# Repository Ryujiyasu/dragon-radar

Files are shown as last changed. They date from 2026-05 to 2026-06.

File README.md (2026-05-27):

# Dragon Radar UWB

> ドラゴンボールの「ドラゴンレーダー」を現代の UWB (Ultra-Wide Band) 測距技術で実物として作るプロジェクト。
> DigiKey Make ONE Challenge 2026 (応募締切 **2026-06-22**) 出展作品。

円形 LCD を載せた手持ち端末が、周囲に散らばった UWB タグ (= ドラゴンボール) の **距離 + 方向 (AoA)** を 5 cm 精度で表示する。UI は 1980 年代バンダイの玩具版ドラゴンレーダーをオマージュ。

詳細仕様は [`dragon-radar-spec.md`](dragon-radar-spec.md)。背景・設計判断・進捗の物語は本 README とブログ記事 ([Related reading](#related-reading)) で記録する。

---

## What works today (2026-05-19 時点)

| 項目 | 状態 | 観測値 |
|---|---|---|
| 2BP ↔ 2DK ranging 成立 | ✅ | 50–60 秒で 200+ サンプル、両端 avg 距離差 < 0.5 cm |
| AoA 方位取得 | ✅ | -44° 安定 (左方向に 2DK 配置時) |
| ESP32-P4 で Bandai 風 UI 描画 | ✅ | 800×800、LVGL 9.5、5 Hz 更新 |
| QN9090 カスタム FW で `RADAR,t=...` ASCII 出力 | ✅ | 3 Mbps UART、~5 Hz |
| ESP32-P4 ↔ 2BP 物理 UART 配線 | ⏳ | TP48→GPIO47 / TP47→GPIO48 / GND、配線待ち |
| 2DK タグ × 7 個拡張 | 未 | Phase 3 以降 |
| 効果音 + BGM | 未 | Phase 4 以降 |

---

## 採用アーキテクチャ: Path C (二段構え)

```
Stage 1 (~6/22)  : Path C (QN9090 カスタム FW)         → DigiKey 応募
Stage 2 (~9月)   : 2DK タグ × 7 個拡張 + 演出           → Maker Faire Tokyo 2026
Stage 3 (将来)   : Path B (ESP32 ↔ SR150 SPI 直結) 移植 → QN9090 を取り払いコスト/サイズ削減
```

Path C は QN9090 (Murata EVK 標準搭載の host MCU) をそのまま使い、その上で動くファームを NXP UWBIOT SDK ベースで自作する路線。

---

## ハードウェア

| 役割 | 型番 | 数 |
|---|---|---|
| プレイヤー機 UI / ホスト | **Waveshare ESP32-P4-WIFI6-Touch-LCD-3.4C** (800×800 round IPS) | 1 |
| 旧 UI 予備 | Waveshare ESP32-S3-Touch-LCD-1.85 | 1 |
| プレイヤー機 UWB (initiator + AoA) | **Murata Type 2BP EVK Rev 4.1** (SR150 + QN9090) | 1 |
| タグ (responder) | **Murata Type 2DK EVK** (SR040 + QN9090) | 2 |
| デバッガ (任意) | NXP MCU-Link Pro | 1 |
| 書込ツール | **`spsdk` (`dk6prog`)** — USB ISP 経由、SWD 不要 | — |

> ⚠️ 技適制約: ESP32-P4 ボード上の ESP32-C6 (WiFi6 コンパニオン) は技適マーク未確認のため、**WiFi/BT は使用しない方針**。2BP ↔ ESP32-P4 は物理配線で接続する。詳細は [#5 技適記事](https://yasu-home.com/?p=37) 参照。

---

## システム構成 (Path C / Stage 1)

```
┌──────────────────────────────────┐         ┌───────────────────────────────┐
│   ESP32-P4 (Waveshare 3.4C)      │         │   Murata 2BP EVK Rev 4.1      │
│                                  │  TP48   │                               │
│   LVGL 9 (Bandai 風 UI)          │ ◄────── │   QN9090 (UCI host)           │
│   uwb_uart_task (3 Mbps)         │ GPIO47  │     │                         │
│   parse RADAR ASCII              │   GND   │   SR150  ◄── UWB 6.5GHz ──┐   │
│   polar → radar pixel            │ ──────  │     (initiator + 3-ant AoA)│   │
└──────────────────────────────────┘         └───────────────────────────────┘
                                                                              │
                                              ┌───────────────────────────────┘
                                              ▼
                                    ┌───────────────────────────────┐
                                    │   Murata 2DK EVK × 2          │
                                    │   QN9090 (Murata standalone)  │
                                    │   SR040 (responder)           │
                                    └───────────────────────────────┘
```

UART payload format (QN9090 が 3 Mbps で吐く 1 行):

```
APP     :INFO :RADAR,t=0,d=21,az=-44.18,el=-60.0,st=0
                       │   │      │           │       │
                       │   │      │           │       └── status: 0=OK
                       │   │      │           └────────── elevation (Q9.7 deg)
                       │   │      └────────────────────── azimuth   (Q9.7 deg)
                       │   └────────────────────────────── distance (cm)
                       └──────────────────────────────── tag id
```

---

## SDK バージョン整合 (最重要)

2BP (SR150) と 2DK (SR040) は **UCI プロトコルの世代を揃えないと ranging が成立しない**。詳細は [#3 UCI 世代差記事](https://yasu-home.com/?p=35)。

| EVK | 採用 FW | UCI 世代 | session ID |
|---|---|---|---|
| 2BP (SR150) | NXP UWBIOT SDK **v04.04.03** ベースのカスタム FW | **1.31** | 0x11223344 |
| 2DK (SR040) | Murata Standalone **v04.03.14** プリビルド (校正済) | **1.31** | 0x11223344 |

UCI v2.0 系 (v04.06.00+) と v1.x 系を混在させると、RANGE_DATA_NTF の `session ID` フィールドの意味が変わる (handle vs ID) ためペアリング不成立。

---

## ディレクトリ

```
dragon-radar/
├── firmware/
│   ├── esp32-p4/                   # ESP-IDF v5.5.4 (UI + UART parser + game)
│   │   ├── main/
│   │   │   ├── ui/                 # radar_view, theme (Bandai colors)
│   │   │   ├── uwb/                # uwb_uart (3Mbps RADAR parser), uwb_filter
│   │   │   ├── game/               # ドラゴンボール検知ゲーム
│   │   │   ├── audio/              # I2S WAV (BGM / SE)
│   │   │   └── storage/            # microSD (FATFS)
│   │   └── sdkconfig.defaults
│   ├── 2bp-fw/                     # 2BP の QN9090 用カスタム FW (Path C)
│   ├── 2dk-fw/                     # 2DK の QN9090 用 FW (将来 Responder 自前ビルド)
│   └── 2bp-config/                 # ★ NDA 配下、gitignore
│       ├── docs/                   # Murata 提供 PDF
│       ├── sdk/                    # NXP UWBIOT SDK + Murata パッチ
│       ├── firmware-backups/       # 工場 FW dk6prog ダンプ
│       └── firmware-builds/        # 自前ビルド済みバイナリ
├── docs/
│   └── 2bp-protocol.md             # ESP32 ↔ QN9090 ASCII プロトコル仕様
├── assets/
│   ├── audio/                      # WAV (神龍 / ウーロン / SE)
│   └── images/                     # PNG (光点, 龍, 星)
└── tools/                          # PC 側スクリプト
```

---

## ビルド

### ESP32-P4 ファーム

```bash
. ~/esp/esp-idf-v5.5/export.sh
cd dragon-radar/firmware/esp32-p4
idf.py build
idf.py -p /dev/ttyACM0 flash monitor
```

GPIO 割当 ([uwb_uart.h](dragon-radar/firmware/esp32-p4/main/uwb/uwb_uart.h)):

| ESP32-P4 GPIO | 2BP EVK TP | 信号 |
|---|---|---|
| GPIO 47 (UART1 RX) | **TP48** | RADAR ASCII (3 Mbps) |
| GPIO 48 (UART1 TX) | **TP47** | 制御送信 (optional) |
| GND | GND (TP29 等) | — |

⚠️ 番号交差注意: 2BP **TP48** ↔ ESP32 **GPIO47**、2BP **TP47** ↔ ESP32 **GPIO48**。

### 2BP QN9090 カスタム FW (NXP UWBIOT SDK)

MCUXpresso IDE の headless build を使う ([#2 MCUXpresso 記事](https://yasu-home.com/?p=34))。

```bash
xvfb-run --auto-servernum --server-args="-screen 0 1024x768x24" \
  /usr/local/mcuxpressoide-25.6.136/ide/mcuxpressoide \
  -nosplash \
  -application org.eclipse.cdt.managedbuilder.core.headlessbuild \
  -data /tmp/mcux-ws \
  -import dragon-radar/firmware/2bp-config/sdk/UWBIOT_SR150_v04.04.03_MCUx/uwbiot-top/project/RhodesV4_SE \
  -cleanBuild "RhodesV4_SE/Debug"
```

出力: `.../project/RhodesV4_SE/Debug/RhodesV4_SE.bin` (約 350 KB、9.6 秒)。

### 2BP に書込 (USB ISP / SWD 不要)

`dk6prog` (SPSDK 同梱) で書き込む ([#1 dk6prog 記事](https://yasu-home.com/?p=33))。

```bash
# 1. EVK のみ単独で USB 接続、ISP ボタン押しながらリセット
dk6prog listdev                                                    # DM86TTWC を確認
dk6prog -d DM86TTWC read 0 0x9DE00 -o factory_backup.bin           # 工場 FW バックアップ (1 度だけ)
dk6prog -d DM86TTWC erase 0 0x9DE00
dk6prog -d DM86TTWC write 0 dragon-radar/firmware/2bp-config/firmware-builds/2bp_dragon_radar_v0.1.bin
```

### 2DK は Murata 出荷 FW のまま使う

2DK は Murata が標準で `2dk_controlee_v04.03.14.bin` を焼いて出荷しており、これがそのまま v1.31 UCI の responder として動く。**書換不要**。

---

## 開発フェーズ

- [x] **Phase 0**: 環境準備 (NXP SDK / MCUXpresso / SPSDK / Waveshare BSP) + 工場 FW バックアップ
- [x] **Phase 1**: ESP32-P4 + LVGL Bandai レーダー UI (ダミーデータ) ✅ 2026-05-19
- [x] **Phase 2a**: NXP UWBIOT SDK v04.04.03 ヘッドレスビルド検証 ✅ 5/19
- [x] **Phase 2b**: `printRangingData` 改造で `RADAR,t=...` ASCII 出力 ✅ 5/19
- [x] **Phase 2c**: 2BP にカスタム FW 書込 + 3 Mbps UART で実機 RADAR 出力確認 ✅ 5/19
- [x] **Phase 2d-1〜4**: EVK ピン特定 + ESP32-P4 GPIO 選定 + UART parser + LVGL 連携実装 ✅ 5/19
- [ ] **Phase 2d-5**: 物理配線 (TP48→GPIO47 等) + 実機テスト (LCD に実距離+AoA 表示)
- [ ] **Phase 3**: 2DK タグ拡張 (2 個 → 7 個) + round-robin スケジューラ
- [ ] **Phase 4**: 音声 (神龍/ウーロン) + SE + BGM + 検知ゲーム
- [ ] **Phase 5**: 筐体 CAD + 3D プリント + 組立
- [ ] **Phase 6**: デモ動画撮影 + DigiKey 応募 (~6/22)
- [ ] **Phase 7**: Maker Faire Tokyo 2026 (~9/5-6) 持込

---

## 制約と教訓

### 技適制約

Waveshare ESP32-P4-WIFI6-Touch-LCD-3.4C 上の ESP32-C6 (WiFi6 コンパニオン) は技適マーク未確認。
公開展示 (DigiKey、Maker Faire) では電波法的にグレーなので、**WiFi/BT を一切 init しない設計**。
ESP32-P4 ↔ 2BP は物理 UART 配線で代替する。詳細: [#5 技適記事](https://yasu-home.com/?p=37)。

### NDA 配下のファイル

`dragon-radar/firmware/2bp-config/` 以下は **Murata NDA 配下** (公式 PDF、NXP UWBIOT SDK、工場 FW バックアップ等)。
gitignore で完全除外、Git に絶対コミットしない。`.gitignore` で `*` + `!.gitignore` パターン。

`my.murata.com` から取得した PDF/SDK は配布禁止。これらに依存する手順は本 README とブログでは技術概念のみ記述し、ソースコード抜粋やキャリブレーション値は載せない。

### UCI 世代揃え

異なる NXP UWB チップ (SR150 / SR040) を組ませる時は SDK の UCI 仕様世代を揃える。
NTF の session ID フィールドが見た目同じでも、v1.x (ID) と v2.0 (Handle) で意味が違う。
詳細: [#3 UCI 世代差記事](https://yasu-home.com/?p=35)。

---

## Related reading

開発過程の知見をブログ記事に分割公開している (https://yasu-home.com 「IoT・組込み」カテゴリ):

| # | 記事 | URL |
|---|---|---|
| 0 | 連載 #0 ドラゴンレーダーを真面目に作る | [https://yasu-home.com/?p=38](https://yasu-home.com/?p=38) |
| 1 | dk6prog (SPSDK) で QN9090 を USB ISP だけで焼く | [https://yasu-home.com/?p=33](https://yasu-home.com/?p=33) |
| 2 | MCUXpresso IDE の headless build で組込ファームを 10 秒で回す | [https://yasu-home.com/?p=34](https://yasu-home.com/?p=34) |
| 3 | UWB ranging が動かない真犯人は「UCI 世代差」だった話 | [https://yasu-home.com/?p=35](https://yasu-home.com/?p=35) |
| 4 | ESP32-P4 × LVGL で「バンダイ ドラゴンレーダー」風 UI を本気で再現する | [https://yasu-home.com/?p=36](https://yasu-home.com/?p=36) |
| 5 | 技適未確認の WiFi ボードを国内コンテストに出すなら何を捨てるか | [https://yasu-home.com/?p=37](https://yasu-home.com/?p=37) |

---

## ライセンス

本リポジトリ内のオリジナルコード (主に `dragon-radar/firmware/esp32-p4/`) はライセンス未確定。
`dragon-radar/firmware/2bp-config/` 以下は NXP / Murata の NDA 配下で再配布不可。
最終的に MIT または Apache-2.0 で公開予定 (応募完了後)。

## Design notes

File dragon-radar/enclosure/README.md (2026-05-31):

# Dragon Radar UWB — 筐体 (Enclosure)

DigiKey Make ONE Challenge 2026 / プレイヤー機の 3D プリント筐体。

- CAD: **OpenSCAD** (パラメトリック、git 管理)
- 印刷: **FDM / PLA / ベッド ~220mm** (ø 一体造形、分割なし)
- ソース: [`dragon-radar-enclosure.scad`](dragon-radar-enclosure.scad)
- 実測: [`MEASURE.md`](MEASURE.md) — 現物を測って `[MEASURE]/[VERIFY]` を確定する記入シート

## 現状: v0.7 (実機適合 + 印刷前レビュー済)

3 部品クラムシェル。**ボード/ボタン現物を実測してモデル確定**、印刷前の多エージェント
レビューで確定8件(critical含む)を修正済み。外径 **ø122.6 × 厚26.9mm**。
残: 現物合わせの [VERIFY] (バレル径・ナット径・コネクタ開口角度)=テストプリントで詰める。

実測で判明した構成 (→ [`MEASURE.md`](MEASURE.md)):
- 前面=丸ディスプレイ **ø115** (有効 ø87.6) / 背面=四角キャリア **85.5×65** / 総厚 **14**
- マウントネジ4本=上下非対称な台形 (X±41.8 / 左Y32 / 右Y39)
- コネクタ: USB-C(上辺)→**底270°** / USB-A→右0° / microSD→左180° (`carrier_angle=180`)
- ボード固定: **二段締め** (カラーでボード⇔ディスプレイ → バックカバー4本で筐体固定)
- ボタン: ø12メタル(全長24/頭1.7/頭〜ナット6) → タレット cap1.8/protrude14/bore16.5

### 印刷前レビューで修正した主な点 (v0.6→v0.7)
- 🔴 **スナップ溝がトング壁0.4mmを貫通→前面リップ分離** を `wall 2.4→3.2` 等で解消(残壁1.0mm)
- 🟠 着座シェルフをガラス背面平面へ / スカラップ肉盛りを z 拘束(前後面の突き抜け防止)
- 🟡 USB-A開口 11→13mm、ナットねじ代確保(cap 1.8)
- 先行: タレットが角度合成で180°にズレmicroSDと衝突 → +X基準に統一し天面90°へ

```
[前面ベゼル] 表示窓 ø91.6 + 段付きスカート + 環状スナップビード + タレット逃げ
[本体タブ]   側壁 + 段付きトング(溝) + 着座シェルフ + バックカバー用ボス
             + コネクタ開口(底) + 天面ボタンタレット + フィンガースカラップ(3/9時)
[バックカバー] M3×4 ネジ留め + 嵌合リップ + 配線通気
```

### フィンガースカラップ (v0.4)

両手持ちの 3/9 時 (0/180°) に親指レスト。側壁 2.4mm + 内側モジュールで深掘り不可のため、
**局所肉盛りレンズ + 浅い凹み** で最薄壁 ~2.4mm を確保。`scallop_angles=[]` で無効化、
高さ/深さは `scallop_*` 変数で調整。ベゼル占有域 (z≤-7) と干渉しないよう中心 z=-14.5 に配置。

> 副次変更: placeholder コネクタを**底側 (250/270/290°)** に集約 (スカラップと干渉回避 +
> ケーブル底出しが自然)。実機角度は [MEASURE] で確定する。

> 🐞 修正: ネジボスが内壁に 0.5mm 届かず**浮きソリッド**になっていた (CGAL Volumes=6 で発覚)。
> `screw_pcd` を外側へ寄せて壁と一体化 (Volumes=2 = 単一ソリッド)。

### 天面ボタンタレット (v0.3)

⚠ **設計上の制約**: モジュール(ø108)と内壁(ø116)の隙間は片側 ~4mm しかなく、
ø12 ボタンの端子(径方向 15-20mm)を画面高さにラジアル配置すると**必ずモジュールに干渉**する。
→ ボタン専用の張り出し容積=**中空タレット**を天面(+Y, 12時)に設け、端子はタレット内に収め、
**細い配線のみ**を環状隙間→後方空洞へ通す。Bandai ラジアンドラップ天面ボタンと同趣。

| パラメータ | 値 | 備考 |
|---|---|---|
| `turret_od` / `turret_protrude` | ~ø21.7 / 18mm | 突出長 ≈ ボタン全長−パネル [VERIFY] |
| `turret_bore` | ø16.5 | ナット/端子の逃げ径 [VERIFY] |
| `button_dia` / `turret_cap_th` | ø12.3 / 3mm | パネル穴 / パネル厚(≤~5) [VERIFY] |
| `wire_hole_dia` | ø5 | 配線通路(後方空洞へ) |

ボタンは Phase4-5 で配線済の MKBKLLJY 現物がある → 全長・端子長・パネル厚を実測し
`turret_protrude` / `turret_bore` / `turret_cap_th` を確定すること。

### 固定方式 (v0.2 確定)

| 接合 | 方式 | 理由 |
|---|---|---|
| ベゼル ⇔ 本体 | **環状スナップフィット** (連続ビード+溝) | 丸物は自己整列、応力が全周分散で PLA でも堅牢。前面ネジ無しで玩具的外観。工具レス開閉。 |
| バックカバー ⇔ 本体 | **M3 セルフタップ ×4** (後方空洞のボス) | 電池/配線/デバッグで開ける前提。背面ネジは外観に影響せず確実。 |

スナップ諸元: スカート厚 `skirt_wall=2.0`、トング高 `tongue_h=7.0`、ビード/溝 径方向 `snap_bead=0.9`、
リードイン `snap_lead=0.8`。外周は本体壁とスカートで **ø121 面一**。
嵌合確認は `-D clip=true` で Y>=0 半割り断面を表示できる。

## レンダリング / 書き出し

OpenSCAD GUI で開き、先頭の `part` 変数を切替えてプレビュー。
印刷用 STL は一括スクリプトで書き出す (生成物は `stl/`、git 管理外):

```bash
# PATH に openscad があれば:
./export-stl.sh
# AppImage を展開して使う場合:
OPENSCAD=/path/to/AppRun FN=180 ./export-stl.sh
```

`part` の値: `assembly`(確認) / `bezel` / `body` / `back` / `board`(mock) /
`coupon_body` / `coupon_bezel` / `coupon`(嵌合確認) / `-D clip=true`(半割り断面)

### スナップ試しクーポン (テストプリント)

`coupon_body` と `coupon_bezel` は嵌合部だけを底側 55° アークで切り出した小片
(実部品と同一ジオメトリ)。フル印刷の前にこの 2 つを印刷して
**寸法フィット** (ビードが乗り越える/座る、`fit_gap` の渋さ、リードインの掛かり) を検証する。

- 検証できる: 径方向の嵌め合い・ビード乗り越え・座面
- 検証しきれない: 全周フープのしなり「カチッ」感 (短アークは実機より硬い) → 最終はベゼル実物で確認
- 調整する変数: `snap_bead`(0.9) / `fit_gap`(0.3) / `snap_lead`(0.8)

### 印刷の向き (推奨)

| 部品 | 向き | サポート |
|---|---|---|
| bezel | 前面を下 (窓側を造形ベッド) | 不要〜軽微。スカート内ビードはオーバーハングだが lead で自立 |
| body | 開口(前面)を上、バック側を下 | タレットの張り出し下面に少量。トング/溝は縦で良好 |
| back | 平面を下 | 不要 |
| coupon | body=トングを上 / bezel=面を下 | 不要 |

## 寸法の出典と確度

### [確定] Waveshare 3.4C 実寸 (wiki 寸法図 + CNX 記事)

| 項目 | 値 | 出典 |
|---|---|---|
| ガラス/前面外形 | **ø115 mm** | CNX「115×115 Outline」 |
| 有効表示エリア | **ø87.6 mm** (800×800, 3.4") | CNX「87.6×87.6 Display area」 |
| 前面ガラス厚 | ~6 mm | wiki 側面図 (4C 図から類推) |
| モジュール総厚 | ~15 mm | wiki 側面図 |

> 注: wiki 寸法図 (ø126 / ø101.52 / 厚15) は **4 インチ版 (4C)** のもの。
> 3.4C はそれより一回り小さい ø115 / ø87.6。仕様書の「ø110」想定より実機は大きく、
> **筐体外径は ~ø121 mm**(下記計算)になる。`dragon-radar-spec.md` の筐体寸法は要更新。

出典:
- https://www.waveshare.com/wiki/ESP32-P4-WIFI6-Touch-LCD-3.4C
- https://www.cnx-software.com/2025/06/01/esp32-p4-development-board-features-3-4-inch-or-4-inch-round-ips-touchscreen-display/

### [要実測 MEASURE] ボード到着後に現物確定する項目

`.scad` 内で `[MEASURE]` 印を付けた変数。実測値を入れれば全体が追従する。

| 変数 | 仮置き | 確定方法 |
|---|---|---|
| `mount_count` / `mount_pcd` / `mount_hole_dia` / `mount_angle0` | 4 / ø105 / ø2.5 / 45° | マウント穴を実測 (PCD・本数・径・基準角) |
| USB-C / USB-OTG / microSD のリム角度・開口寸法 | `connector_cutout()` 3 箇所が仮 | 各コネクタの周方向位置と高さを実測 |
| `back_clear` | 8 mm | 背面コネクタ群の最大突出 + 電池/配線スペース |
| `button_z` | スタック中央 | MKBKLLJY ボタンの実装高さ |

### 筐体派生寸法 (現状の仮値での計算結果)

| 寸法 | 値 |
|---|---|
| 内壁径 `inner_dia` | ~116.2 mm |
| **外径 `outer_dia`** | **~121.0 mm** |
| 表示窓径 `window_dia` | ~91.6 mm (有効表示 ø87.6 を完全露出) |
| **筐体総厚 `outer_depth`** | **~27.9 mm** (仕様目標 30mm 以内 ✅) |

## 印刷設定 (FDM / PLA、初版の目安)

| 項目 | 値 | 備考 |
|---|---|---|
| ノズル / 層厚 | 0.4mm / 0.2mm | 側壁 `wall=2.4` は 0.4×6 で割り切れる |
| 壁ライン数 | 3–4 | |
| インフィル | 15–20% gyroid | |
| サポート | ベゼル窓まわり程度 | 各部品は概ね自立印刷向き |
| 向き | ベゼル=窓を上 / 本体=開口を上 / バック=平面下 | |

## 次のステップ (ボード到着前にできる事 / 到着後)

- [x] `dragon-radar-spec.md` の筐体寸法を ø110→ø121 に更新
- [x] ベゼル⇔本体の固定方式決定 → 環状スナップ + バックM3ネジ (v0.2)
- [x] 天面ボタンタレット (MKBKLLJY ø12+LED) を配置・中ぐり・配線通路 (v0.3)
- [x] フィンガースカラップ (3/9時) + ネジボス浮き修正 (v0.4)
- [x] スナップ試しクーポン + STL一括書き出し (B-1/B-3)
- [ ] 【A】現物実測: コネクタ角度/マウント穴 PCD/ボタン各寸法 → 各 [MEASURE]/[VERIFY] 確定 ← 次
- [ ] ボタン現物を実測 → `turret_protrude`/`turret_bore`/`turret_cap_th` 確定
- [ ] マウントボスをネジ種 (M2.5 セルフタップ or インサート) に合わせて確定
- [ ] ストラップ/手持ち形状、滑り止め
- [ ] テストプリント (スナップ嵌合 + タレット嵌め込みの現物確認)

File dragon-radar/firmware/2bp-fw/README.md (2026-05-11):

# 2BP QN9090 カスタムファームウェア (Path C)

ESP32 ↔ 2BP の自前 ASCII プロトコル ([../../docs/2bp-protocol.md](../../docs/2bp-protocol.md)) を喋り、内部で SR150 を UCI で叩いて round-robin Unicast TWR を実行する QN9090 用ファーム。

## 必要な前提

- NXP UWBIOT SDK SR150 v04.06.00 (要 NXP MyAccount)
- Murata 提供パッチ (`2bp_prebuilt_*.patch`、my.murata.com から取得)
- MCUXpresso IDE (Linux 版、無料)
- MCU-Link Pro (SWD 書込用)
- ARM GCC toolchain (`arm-none-eabi-gcc`)

## SDK 配置 (gitignore 内)

NXP からダウンロードした SDK は **NDA 配下** のため、コミット禁止。下記に展開する:

```
firmware/2bp-config/
├── docs/                             # Murata PDF (取得済)
└── sdk/                              # ★ ここに SDK を展開
    ├── UWBIOT_SR150_*_SEGGER/
    └── 2bp_prebuilt_*.patch
```

`firmware/2bp-config/.gitignore` で全配下が除外されているので安全。

## ビルド手順 (Phase 1 で確定)

```bash
# 1. SDK ディレクトリへ
cd firmware/2bp-config/sdk/UWBIOT_SR150_*_SEGGER/uwbiot-top

# 2. Murata パッチ適用 (Quick Start PDF 参照)
patch -p0 < ../2bp_prebuilt_*.patch

# 3. デモ ranging controller を 2BP の QN9090 用に make
cd boards/Host/Rhodes4
make demo_ranging_controller TARGET=QN9090

# 4. JLinkExe で書込み (MCU-Link Pro が J-Link 互換ファーム)
JLinkExe -device QN9030 -if SWD -speed 4000 -CommandFile flash.jlink
```

## 開発ステップ

| Phase | やること |
|---|---|
| 1 | SDK + パッチ適用 → Murata 出荷 FW 相当をビルド・書込・動作確認 |
| 2 | UART パーサ (ASCII) を組み込み、`VER`/`RANGE` (1タグ) 実装 |
| 3 | `SET_TAGS` / round-robin (2 タグ対応) |
| 7 | round-robin の 7 タグ対応、サイクル時間最適化 |

## ファイル配置 (Phase 2 で実装予定)

```
2bp-fw/
├── README.md       (このファイル)
├── src/
│   ├── main.c          # FreeRTOS エントリ
│   ├── uart_cmd.c/h    # ASCII コマンドパーサ
│   ├── ranging.c/h     # round-robin スケジューラ
│   └── config.h        # SR150 設定、タグ MAC 一覧
└── prj/                # MCUXpresso プロジェクト一式
```

## デバッグ Tips

- 元の Murata プリビルド FW に戻すには Phase 0 で取得した `firmware-backups/2bp_qn9090.bin` を JLink で書き戻す
- UART 出力は MCU-Link Pro の Bridge UART で覗ける (Virtual COM)
- SR150 への UCI コマンド送信前に必ず `phNxpUciHal_init()` を呼ぶ (校正データロード)

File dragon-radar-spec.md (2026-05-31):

# Dragon Radar UWB - 開発指示書 (Path C / 二段構え版)

DigiKey Make ONE Challenge 2026 応募作品。Murata UWB EVK + Waveshare ESP32-S3-Touch-LCD-1.85 でドラゴンレーダー風の宝探しデバイスを作る。子供と公園で 2-7 個のタグを探し、全部集めると神龍が召喚されてウーロンが「ギャルのパンティおくれーっ」と叫ぶ。

応募締切: **2026-06-22 23:59** (残り **42 日** / 起算 2026-05-11)
GW (4/29-5/6) 終了、平日モード移行。子守再開済で開発時間は **夜 + 週末**。
本ドキュメントは Claude Code への開発指示書として使用する。

---

## 採用方針: **Path C** (QN9090 ファーム書換え)

### Path 比較サマリ (詳細別途検討済)

| Path | 概要 | 採否 | 理由 |
|---|---|---|---|
| Path A | Murata プリビルド FW のまま | ❌ | 2DK が Initiator 固定でタグにできない |
| Path B | QN9090 erase + ESP32 が SR150 を SPI 直叩き | ❌ (今回) | 工数大、2BP 1個で破壊リスク高 |
| **Path C** | **QN9090 にカスタム FW、ESP32 ↔ QN9090 は UART** | ✅ **採用** | 工数中、ハード改造ゼロ、戻せる |

### 二段構え戦略

```
[Stage 1] 5月中: Path C で実装 → 6/22 応募 (実演 2 タグ + 演出で 7 タグ)
[Stage 2] 7-8月: Path B (ESP32 で SR150 を直接制御) に移植チャレンジ
[Stage 3] 9/5-6: Maker Faire Tokyo 2026 出展 (進化版)
```

---

## ハードウェア構成

### 現有機材 (2026-05-03 時点)

| 役割 | 型番 | 数 | 状態 / 備考 |
|---|---|---|---|
| プレイヤー機 UI (旧) | Waveshare ESP32-S3-Touch-LCD-1.85 | 1 | ESP32-S3 + 1.85" 丸型 LCD (360×360, ST77916)。画面が小さく、Bandai 玩具感は出るが「ガチ路線」のため格上げ予定 |
| **プレイヤー機 UI (新) ⭐** | **Waveshare ESP32-P4-WIFI6-Touch-LCD-3.4C** | **1 (発注予定)** | **ESP32-P4 + ESP32-C6 (Wi-Fi6/BT5、未使用)、3.4" 丸型 LCD (800×800, MIPI-DSI 2-lane)、10 点タッチ、デュアルマイク、microSD。$80-90、DigiKey 発注予定** |
| プレイヤー機 UWB | Murata Type 2BP EVK (LBUA0VG2BP-EVK-P) | 1 | NXP **SR150** (距離+AoA可) + QN9090 MCU。Path C では QN9090 にカスタム FW を焼く |
| タグ #1, #2 | Murata Type 2DK EVK (LBUA2ZZ2DK-EVK) | 2 | NXP **SR040** (距離のみ) + QN9090 MCU。CR2032 駆動可、隠して放置できる。Path C で Responder 化 |
| デバッガ/SWD 書込 | NXP MCU-Link Pro | 1 | QN9090 へのカスタム FW 書込用、Bridge UART/Target Power 機能あり |
| 用途未確定 | EA-WO1391-1228 (Embedded Artists 系?) | 1 | Phase 0 で正体特定すること |

### UI 操作系の仕様 (確定)

**物理ボタン × 1 + タッチスクリーン + 音声トリガ の三段構え**:

| 操作系 | 用途 | 実装時期 |
|---|---|---|
| **物理ボタン (MKBKLLJY ø12mm メタル + 緑 LED、配線済)** | スキャン開始 / 一時停止 (アニメリスペクト) + 神龍 LED 演出 | Phase 4-5 |
| **タッチスクリーン (10 点)** | ズーム、タグ情報表示、設定メニュー | Phase 2-3 |
| **音声トリガ (デュアルマイク)** | 「ドラゴンボールを探せ!」で起動 | Phase 7 (Maker Faire 用) |

筐体上部に **MKBKLLJY 緑 LED モメンタリ ボタン (ø12mm)** を配置 (Bandai 玩具と同位置)。
押下時に「ピッ」効果音 (VOICEVOX 生成)、待機中は LED 呼吸光、神龍召喚時は LED 高速点滅。
LED は 12V 仕様なので、ESP32 GPIO から MOSFET で 5V (USB-C 5V) を ON/OFF する構成。

### 機材についての追記
- 2BP EVK のヘッダピン (10ピン×2列) が一部曲がっているが、**Path C では USB ケーブルのみで動作するため影響なし**
- 2BP EVK は **1 個しか保有しない方針** (高価なため、破損時のみ追加発注)
- 2DK EVK の追加 5 個は **6/22 応募後 (7月頃) に発注予定** (Maker Faire 7 タグ拡張用)
- **プレイヤー機 LCD は 1.85" → 3.4" に格上げ決定** (動画映え重視、ESP32-S3 → ESP32-P4 への移行が必要):
  - 旧 1.85" (ESP32-S3-Touch-LCD-1.85) は予備 / Phase 2 検証用に保管
  - 新 3.4" (ESP32-P4-WIFI6-Touch-LCD-3.4C) は 5/4 発注、5/12 頃着想定
  - 筐体: **外径 ~ø122.6mm × 厚 ~26.9mm** (両手持ち or 大人片手、Bandai より大きいが解像度 800×800 で迫力)
    - 3.4C 実寸(実測確定): 前面=丸ディスプレイ **ø115**(有効 ø87.6) / 背面=四角キャリア **85.5×65** / モジュール総厚 **14**
    - OpenSCAD パラメトリック筐体は [`dragon-radar/enclosure/`](dragon-radar/enclosure/) (v0.7: 実機適合 + 印刷前多エージェントレビュー済)
    - マウントネジ4本=上下非対称台形、コネクタ USB-C底/USB-A右/microSD左、天面ボタンタレット、二段締め固定。残は現物合わせ [VERIFY]
  - 移行作業: ESP-IDF target esp32s3→esp32p4、display_init.c (SPI ST77916 → MIPI-DSI)、LVGL 寸法定数 (360 → 800)、半日〜1日工数

### 9月 Maker Faire 用追加発注 (7月予定)

| 部品 | 数 | 概算 |
|---|---|---|
| 2DK EVK 追加 | 5 | ~$450 |
| (オプション) 自作タグ PCB 部品一式 | 1 セット | ~$300 |

---

## システムアーキテクチャ (Path C)

```
[ プレイヤー機 (筐体内部) ]
┌─────────────────────────────────────────────┐
│ Waveshare ESP32-S3-Touch-LCD-1.85          │
│  ├─ LVGL UI (丸型レーダー)                  │
│  ├─ ゲームステートマシン                    │
│  ├─ 音声再生 (I2S)                         │
│  ├─ microSD (asset)                         │
│  └─ UART パーサ (シンプル ASCII)            │
└──────┬──────────────────────────────────────┘
       │ UART or USB-CDC
       │ "RANGE" → "OK TAG1:1234,30,−5 TAG2:2100,−15,40"
       ▼
┌─────────────────────────────────────────────┐
│ Murata Type 2BP EVK                         │
│  ├─ QN9090 MCU ← カスタム FW (我々が書く)   │
│  │   - NXP UWBIOT SDK ベース               │
│  │   - UCI Host stack (NXP 提供)           │
│  │   - 自作 ASCII コマンド I/F             │
│  │   - 1:N (round-robin) ranging           │
│  └─ SR150 UWB IC (Murata 校正済)           │
└─────────────────────────────────────────────┘
                ↑ UWB 電波
                │
[ タグ × 2 (公園に隠す)、各々独立動作 ]
┌──────────────────────┐  ┌──────────────────────┐
│ Murata Type 2DK EVK  │  │ Murata Type 2DK EVK  │
│  ├─ QN9090 ← Responder FW │  │  ├─ QN9090 ← Responder FW │
│  └─ SR040 UWB IC     │  │  └─ SR040 UWB IC     │
│  ├─ CR2032 電池駆動   │  │  ├─ CR2032 電池駆動   │
└──────────────────────┘  └──────────────────────┘

[ 開発・デバッグ時のみ ]
┌─────────────────────────────────────────────┐
│ MCU-Link Pro (NXP)                          │
│  └─ SWD で QN9090 にファーム書込・デバッグ  │
└─────────────────────────────────────────────┘
```

### データフロー

1. ESP32 が QN9090 に "RANGE" コマンド送信 (33ms 間隔, 約 30Hz)
2. QN9090 が **round-robin で 2 タグ (将来 7) を順番に Unicast TWR 実行**
3. 各タグの距離 (mm) + 方位角 (deg) を集計
4. QN9090 が ESP32 に "OK TAG1:1234,30 TAG2:2100,-15" のような ASCII レスポンス
5. ESP32 がパース → LVGL レーダーに光点プロット
6. ゲームロジックが「30cm 以内に N 秒滞在 = 取得」を判定
7. **2 個取得時点** で 7 個取得演出に分岐 (動画用) or **7 個取得** (Maker Faire 拡張時)
8. 神龍召喚演出 + ウーロン音声 + パンティひらひらアニメ

---

## ディレクトリ構成

```
dragon-radar/
├── README.md
├── firmware/
│   ├── esp32-s3/                # ESP-IDF プロジェクト (UI + ゲーム + UART parser)
│   │   ├── main/
│   │   │   ├── main.c
│   │   │   ├── display_init.c   # ST77916 + LVGL 初期化 (Waveshare driver 取込予定)
│   │   │   ├── ui/
│   │   │   │   ├── radar_view.c/h     # LVGL レーダー UI ✅ 5/3 実装済
│   │   │   │   ├── summon_view.c/h    # 神龍召喚演出
│   │   │   │   └── theme.c/h           # 色・フォント定義
│   │   │   ├── uwb/
│   │   │   │   ├── uwb_uart.c/h        # QN9090 への UART コマンド I/F
│   │   │   │   └── uwb_filter.c/h      # 移動平均・異常値除去
│   │   │   ├── game/
│   │   │   │   └── game_state.c/h
│   │   │   ├── audio/
│   │   │   │   └── audio_player.c/h    # I2S 再生
│   │   │   └── storage/
│   │   │       └── sd_card.c/h
│   │   ├── components/                 # ST77916 driver 等
│   │   ├── CMakeLists.txt
│   │   ├── sdkconfig.defaults
│   │   └── partitions.csv
│   ├── 2bp-fw/                  # ★ Path C で新設: 2BP の QN9090 用カスタム FW
│   │   ├── README.md            # MCUXpresso での開発手順
│   │   ├── src/
│   │   │   ├── main.c                  # FreeRTOS エントリ
│   │   │   ├── uart_cmd.c/h            # ASCII コマンドパーサ
│   │   │   ├── ranging.c/h             # round-robin ranging スケジューラ
│   │   │   └── config.h                # SR150 設定、タグ MAC 一覧
│   │   └── prj/                  # MCUXpresso プロジェクトファイル
│   ├── 2dk-fw/                  # ★ Path C で新設: 2DK の QN9090 用 Responder FW
│   │   ├── README.md
│   │   ├── src/
│   │   │   ├── main.c
│   │   │   └── responder.c/h           # SR040 を Responder として常駐
│   │   └── prj/
│   └── 2bp-config/              # Murata 公式ドキュメント (NDA, gitignore)
│       └── docs/                # 取得済 Murata PDF 25 件
├── assets/
│   ├── audio/                          # VOICEVOX で事前生成
│   │   ├── search_beep.wav
│   │   ├── found.wav
│   │   ├── shenron_appear.wav
│   │   ├── oolong.wav
│   │   └── shenron_grant.wav
│   └── images/
│       ├── star.png
│       ├── shenron.png
│       └── panty.png
├── tools/
│   ├── uart_sniffer.py                  # PC で QN9090 UART を眺めるツール ✅ 5/3 実装済
│   └── captures/                        # raw キャプチャログ (gitignore)
└── docs/
    ├── 2bp-protocol.md                  # 2BP↔ESP32 ASCII プロトコル仕様
    ├── path-c-architecture.md           # Path C アーキテクチャ詳細
    ├── demo-scenario.md                 # 動画台本
    └── parts-list.md                    # myLists 用部品表
```

---

## 開発スケジュール (Path C / 二段構え)

### 現状 (2026-05-11 時点) ✅ 達成済み

- ESP-IDF v5.3.2 インストール (esp32p4 ターゲット対応確認済)
- ARM GCC 13.2 + J-Link Commander インストール
- `dragon-radar/` プロジェクト初期化
- ESP-IDF プロジェクトスケルトン (LVGL 9.2 取込、ビルド成功) - 旧 1.85" 用
- **Phase 2 (LVGL レーダー UI)** 実装済: ダミーデータで光点が動く
- Murata PDF 25 件取得 (NDA 配下、gitignore)
- 2BP/2DK Quick Start Guide 解析、**Path C 採用決定**
- **NXP UWBIOT SR150 v04.08.01 MCUx SDK 取得・展開済** (NDA 配下)
- **Waveshare ESP32-P4-WIFI6-Touch-LCD-3.4C 5/11 着** (本体 + 大型スピーカー)
- ESP32-S3 → ESP32-P4 移行方針確定

## 5/19 Phase 1 完了報告 + Phase 2 引継ぎ

**完了済 (5/19)**

| 項目 | 状態 | 場所 |
|---|---|---|
| ESP-IDF v5.5.4 + esp32p4 ターゲット | ✅ | `~/esp/esp-idf-v5.5` |
| ARM GCC 13.2, J-Link Commander | ✅ | `~/tools/`, `/opt/SEGGER` |
| MCUXpresso IDE for Linux | ✅ | `/usr/local/mcuxpressoide-25.6.136` |
| SPSDK dk6prog (USB ISP 書込) | ✅ | `pip install spsdk` |
| ESP32-P4-WIFI6-Touch-LCD-3.4C | ✅ 動作確認済 (Bandai 風 UI) | `firmware/esp32-p4/` |
| 2BP/2DK ×2 出荷時 FW バックアップ | ✅ 3 ファイル | `firmware/2bp-config/firmware-backups/` (gitignore) |
| 2BP に 2bp_controller_v04.08.01.bin 書込 | ✅ dk6prog 経由 | - |
| 2DK ×2 に 2dk_controlee_v04.03.14.bin 書込 | ✅ dk6prog 経由 | - |
| Murata PnP script 取得 (SR150 + SR040) | ✅ | `firmware/2bp-config/sdk/MTD-SCP-*` |

**観測値 (5/19 実機計測)**

- 2BP RANGE_DATA_NTF 内の Session 識別子: `0x00000001` (Session Handle と推測)
- 2DK RANGE_DATA_NTF 内の Session 識別子: `0x11223344` (Session ID そのまま)
- → 一見「Session ID 不一致」に見えるが、SDK source 確認結果 **両方とも内部設定は `0x11223344`** で一致
  (`demos/SR1XX/demo_ranging_controller/demo_ranging_controller.c:31` および
   `demos/SR040/demo_tracker_sr040/app_Ranging_Cfg.h:17` で定義)
- → 実際の原因は **UCI プロトコル仕様の世代差** (v04.08.01 は UCI 2.0+ で Session Handle 採用、
  v04.03.14 は旧 UCI で Session ID 直接表記) と推定
- → **2BP/2DK の UCI バージョンを揃える** ことが ranging 完成の鍵
- Murata 2bp_prebuild パッチは session ID を変更しない (TX_POWER + XTAL_CAP 校正と ranging timeout 5→30 分のみ)
- 2DK は SR040 へ毎起動で SWUP (Software Update) push が必要 (host script が ~30 秒で 275 component を転送)
- FTDI 工場シリアル: 全 EVK 同じ `DM86TTWC` (個体識別性なし、bus address で区別)
- dk6prog PYFTDI backend は **要 sudo** (USB raw access のため)
- dk6prog の引数: `-d DM86TTWC` で接続、`read/erase/write -o file 0x0 0x9DE00` で操作

**機材コンディション (5/19 時点)**

- 2BP の SR150 SPI ブレークアウトピン (TP20/TP81-87 周辺、2x4 ヘッダ): 一部曲がり/欠損
  → Path C では使わないので**実害なし**
- 2BP の QN9090 SWD ピン: **状態不明** (Quick Start 図と一致するコネクタを未特定)
  → USB ISP モード (dk6prog) で代替できているので、現状問題なし
- 2DK の SWD ピン: **生存**
  → 必要なら J-Link でデバッグ可能、Phase 2 開発時の保険として有用
- USB-A to Micro-B データ通信対応ケーブル: 必須 (充電専用品は不可)

**Phase 2 への引継ぎ事項**

1. **session ID 統一** が ranging 完成の鍵
   - 自前ビルド時に `Demo_Common_Config.c` の `SESSION_ID` を 2BP/2DK 両者で揃える
   - 推奨: `0x00112233` のような固定値、両側のソースを編集して再ビルド
2. **NXP UWBIOT SDK で MCUXpresso 上でビルド** (PDF: `Type 2BP How to Build Pre-Built Binary.pdf` 参照)
   - 2BP: SR150 SDK v04.08.01 のソース + Murata パッチ `2bp_prebuild_v04.08.01.patch`
   - 2DK: SR040 SDK v04.03.14 のソース + Murata パッチ `2dk_prebuilt_v04.03.14.patch`
3. **ESP32 ↔ QN9090 ASCII プロトコル** 実装 ([docs/2bp-protocol.md](dragon-radar/docs/2bp-protocol.md) 参照)
4. 校正値は 2BP/2DK 個体ごとに記録 (`UWB_DeviceConfig_SR1XX.h`)、Murata パッチで適用される
5. 万一書込ミスったら **firmware-backups/** から `dk6prog write 0x0 <backup>.bin` で原状復帰可能

**Phase 1 検証で得た知見 (将来トラブルシュート用)**

| 症状 | 原因/対処 |
|---|---|
| `Sem Timed out` / `UwbApi_Init Failed` | SR040 への SWUP 未完了、or SR150 と SR040 の SDK バージョン不整合 |
| `UCI Header is not valid` 連発 | QN9090 がまだ ISP モード (リセット必要) / FW バージョン不一致 |
| `2 USB devices match URL` | dk6prog は同シリアル 2 台同時不可、片方を物理切断 |
| `--enable-non-contiguous-regions discards section ... 21KB` | ESP32-P4 v1.x シリコンで `CONFIG_SPIRAM_XIP_FROM_PSRAM` 有効だと IRAM 溢れ → 無効化 |
| 起動 garbage 出力で baud 合わない | ISP モードから抜けてない、リセットボタンで物理リセット必要 |

---

## 5/19 Phase 2 ブレイクスルー: 2BP↔2DK Ranging 成立 🐉

**結論**: UCI バージョンを揃えれば **そのまま ranging 通る**。session ID の問題は副次的だった。

**実施した組合せ**

| 役割 | EVK | 書込 FW | UCI ver | 出所 |
|---|---|---|---|---|
| Initiator/Controller | 2BP (SR150 + QN9090) | `demo_ranging_controller-SR150-v04.04.03.bin` | **1.31** | NXP UWBIOT SDK v04.04.03 (Rhodes4_SE 用 bare bin) |
| Responder/Controlee | 2DK (SR040 + QN9090) | `2dk_controlee_v04.03.14.bin` | **1.31** | Murata Standalone v04.03.14 (校正済) |

これまでの v04.08.01 (UCI 2.0) ↔ v04.03.14 (UCI 1.31) では Session Handle/Session ID の表現が違って pair 不成立だったが、**両端を UCI 1.31 に揃えた瞬間に成立**した。

**観測結果 (50–60 秒間の同時計測 / 手元配置 30–50 cm)**

| EVK | サンプル数 | min | max | avg |
|---|---:|---:|---:|---:|
| 2BP (SR150 initiator) | 242 | 24 cm | 55 cm | **36.1 cm** |
| 2DK (SR040 responder) | 296 | 22 cm | 54 cm | **35.6 cm** |

両端で平均値の差 **0.5 cm**、レンジも合致。実距離 (手元 30–50 cm) と整合し、SR040 側で校正済 (Murata パッチ) の効果と思われる。

**この組合せの欠点と次の手**

- 2BP 側は **NXP 公式 Rhodes4_SE バイナリ** を流用しているため、Murata の TX_POWER / XTAL_CAP / 周辺校正が未適用 → 絶対距離精度は妥協ライン。
- AoA はまだ未確認 (TWR distance のみ)。`RANGE_DATA_NTF` の AoA フィールドはパース必要。
- Phase 2 で **Murata SDK v04.04.03 ベースの自前ビルド + 校正値適用** を行えば理想形。
- session ID は両ファームともデフォルトで `0x11223344` 採用なので、自前ビルドでも変更不要。

**意味**

- Phase C のロジックレベルでは「2BP=Initiator、2DK=Responder、両者 UCI 1.31、session=`0x11223344`」が黄金パターン。
- Phase 2 以降 (カスタム QN9090 FW + ESP32 ASCII プロトコル) のターゲット FW バージョンは **NXP SDK v04.04.03 / UCI 1.31** に確定。

---

## Phase 2 着手方針 (5/19 確定)

### ベース SDK: v04.04.03 / Murata 校正なし

| 項目 | 値 |
|---|---|
| ベース SDK | NXP UWBIOT SDK v04.04.03 (`UWBIOT_SR150_v04.04.03_MCUx/uwbiot-top/`) |
| MCUXpresso project | `project/RhodesV4_SE/` (`.project` + `.cproject` あり) |
| Demo | `demos/SR1XX/demo_ranging_controller/demo_ranging_controller.c` |
| Murata 校正 | **適用しない** (v04.04.03 用パッチが Murata から未配布、v04.06.05 用パッチは UCI opcode `2E11→2F21` 差で直接適用不可)。絶対距離精度は妥協、レーダー演出に必要な相対変化は十分得られる。 |
| ビルド方式 | MCUXpresso IDE GUI もしくは `mcuxpressoide -application org.eclipse.cdt.managedbuilder.core.headlessbuild` (CDT headless) |
| 書込 | dk6prog (USB ISP) — Phase 1 と同じ |

### Phase 2 サブタスク

- **2a**. SDK 同梱の `demo_ranging_controller` を **無改変でビルド**。`binaries/Rhodes4_SE/demo_ranging_controller-SR150-v04.04.03.bin` (既に動作確認済の bare bin) と sha 一致を確認 → ビルド環境健全性のチェック。
- **2b**. `libs/uwb-iot/uwb_api/PrintUtility/PrintUtility.c` の `printRangingData()` 内で `NXPLOG_APP_D("TWR[...].aoa_*")` 系を **カスタム ASCII フォーマットに置換**。
  - 提案フォーマット: `RADAR,t=<tag_id>,d=<dist_cm>,az=<az_q9.7>,el=<el_q9.7>,st=<status>\n`
  - APP 層 (NXPLOG_APP_I) で出すことで、既存の `TWR[0].distance` printf と同じ UART/baud で取得可能
- **2c**. 改修バイナリを 2BP に dk6prog で焼く。2DK は v04.03.14 のまま。Murata Python script ではなく ESP32 (もしくは PC ホストテスト) で UART を直 read。
- **2d**. ESP32-P4 側で UART (現状 GPIO 未確定) を初期化し、`RADAR,...` を parse → LVGL `radar_view.c` の光点座標に変換 (極座標 → 直交変換)。

### ASCII プロトコル設計案

ESP32 ← QN9090 (notifier):

```
RADAR,t=0,d=42,az=-15.3,el=2.1,st=0\n     # tag 0 ranging OK
TICK,uptime=12345\n                        # 1Hz heartbeat
LOG,msg=session_started\n                  # 任意ログ
```

ESP32 → QN9090 (control, Phase 2c+ で実装):

```
START\n                                     # ranging 開始
STOP\n                                      # ranging 停止
SET_TAG,id=1,mac=2223\n                    # 7 タグ対応の追加 (Phase B)
```

詳細プロトコル仕様は [docs/2bp-protocol.md](dragon-radar/docs/2bp-protocol.md) に切り出し済み。

### リスクと回避策

| リスク | 回避策 |
|---|---|
| MCUXpresso headless build がうまく動かない | GUI で代替、もしくは `mcuxpressoide-ide -nosplash` の `-application` 指定で試す |
| Build 成果物 bin と Rhodes4_SE 同梱 bin の sha が一致しない | 元の binaries/ にある bin はメーカー署名済の可能性 → 違って当然と見て、動作で確認 |
| AoA Azimuth が 0 で返ってくる | SR150 のアンテナ delay calib 未適用が原因の可能性 → 値が出ていれば校正ズレ程度なので進める |
| `printRangingData` 改修で他デモがビルド不能になる | `#ifdef UWBIOT_APP_BUILD__DEMO_RANGING_CONTROLLER` で囲って影響範囲を限定 |

### Phase 2 実機検証ログ (5/19 16:10)

| 項目 | 値 |
|---|---|
| 2BP FW | `firmware-builds/2bp_dragon_radar_v0.1.bin` (353312 B、v04.04.03 SDK Debug ビルド) |
| 2DK FW | `2dk_controlee_v04.03.14.bin` (出荷時 Murata 校正済) |
| UART baud (debug console) | **3 000 000 bps** (`boards/Rhodes4_SPI/board.h:203`) |
| ranging rate | ~5 Hz (20 秒で 100 行) |
| 距離 (手元配置) | 19–24 cm |
| AoA Azimuth | -44° 〜 -45° (左方向に 2DK、安定) |
| AoA Elevation | -60.0° に固定 (SR150 は方位アンテナのみ、仰角は無効) |
| サンプルログ | `firmware-builds/sample_radar_uart_20s.bin` (35613 B) |

**出力フォーマット例** (3Mbps UART、ANSI色付き):

```
APP     :INFO :TWR[0].distance        : 21
APP     :INFO :RADAR,t=0,d=21,az=-44.18,el=-60.0,st=0
```

ESP32 側パース仕様 (Phase 2d で実装):
- baud: 3000000、ANSI escape (`\e[0;34m`〜`\e[0m`) は除去
- `RADAR,t=<tag>,d=<cm>,az=<int>.<frac>,el=<int>.<frac>,st=<status>` を抽出
- 角度: Q9.7 表記、`real_deg = int_part + (frac/128.0)` (符号は int_part に従う) で復元
- status==0 のみ採用、他は drop
- ranging timeout = 5 分なので再起動時はリセット必要

### Phase 2d-5 完了 (5/19 夜、実機 + LCD 確認済) ✅

ESP32-P4 GPIO47 ← 2BP TP48 の物理配線で、LCD に光点が出ることを確認。
全経路成立: `2DK ─UWB→ 2BP/SR150 → QN9090(RADAR ASCII) → UART線 → ESP32 GPIO47 → parser → radar_view → LCD 光点`。

**実装時に踏んだバグ 2 件 (修正済)**

1. **`radar_view_set_tag()` が `tag_id == 0` を早期 return で drop**
   - QN9090 は `RADAR,t=0` (UWB measurement index は 0-based) を送るが、radar_view は tag_id を 1-based (`s_dots[tag_id-1]`) で扱う設計
   - 修正: parser (`uwb_uart.c`) で `tag_id = t + 1` に変換
2. **`app_main` を return させると表示が消える**
   - この BSP/esp_lvgl_adapter 構成では app_main が return すると static UI ごと消える
   - 修正: app_main 末尾に `while(1) vTaskDelay` を置いて生かし続ける (Phase 1 にあったものを誤って削除していた)

**運用上の注意**

- ~~2BP のカスタム FW は起動後 **5 分で ranging セッションを閉じて停止**~~ → **v0.2 で解消** (下記)。
- 旧 v0.1 の再ペア手順 (参考): ① 2DK を先にリセット → ②数秒後に 2BP をリセット。

**5/29: QN9090 FW v0.2 (連続 ranging 化)**

- `demo_ranging_controller.c` の `delay = 5*60*1000` を `delay = 0xFFFFFFFFUL` に変更 (~49 日 = 実質無限)。
- セッションを張りっぱなしにすることで、**2DK が一旦切れて戻っても自動で再 join** する → 5分制限と手動再ペアの両方を解消。
- ビルド済: `firmware-builds/2bp_dragon_radar_v0.2_continuous.bin` (353304 B)。

**⚠️ ISP 書込時は ESP32↔2BP の配線を外すこと (重要)**

- ESP32 の **GPIO48 (UART TX) → 2BP TP47 (QN9090 PIO_9/USART0_RXD)** が繋がっていると、dk6prog の ISP ハンドシェイク (FTDI が PIO_9 経由でコマンド送信) と**競合して timeout**する。
- 症状: `dk6prog info` が `TimeoutError`、Chip ID が返らない。
- 対処: 書込前に最低限 **TP47↔GPIO48 線を外す** (安全のため 3 本とも外すか ESP32 電源 OFF)。書込後に戻す。
- v0.1 書込時に問題なかったのは、当時まだ配線していなかったため。

### 技適制約 (5/19 確定)

Waveshare ESP32-P4-WIFI6-Touch-LCD-3.4C 基板上の ESP32-C6 モジュールに **技適マーク未確認**。
公開展示 (DigiKey Make ONE Challenge) では電波法違反になり得るため、

**本プロジェクトでは ESP32-P4 ボードの WiFi/BT を一切使用しない方針**。

影響:
- 2BP ↔ ESP32-P4 通信は **物理配線 (UART 直結) で固定** (A2 ルート確定)
- 将来の拡張案 (BLE スマホ連携、WiFi 経由ファーム更新) もこのボードで実現する場合は技適認証品への基板差替を要する
- LCD / Touch / microSD / GPIO など WiFi 以外の機能は使用 OK

### 配線計画 (5/19 EVK Rev4.1 Schematic + Waveshare 3.4C ボード写真確認済)

| 端点 (2BP) | 信号 | 電圧 | 端点 (ESP32-P4) | 補足 |
|---|---|---|---|---|
| **TP48** | QN9090 PIO_8 / USART0_TXD | 3.3V CMOS | **GPIO 47** (UART1 RX) | 主信号 (RADAR 3Mbps) |
| **TP47** | QN9090 PIO_9 / USART0_RXD | 3.3V CMOS | **GPIO 48** (UART1 TX) | optional, 制御送信用 |
| GND (TP29 等) | GND | — | GND | 必須 |

**配線番号の罠**: 2BP 側の "TP48" と ESP32-P4 側の "GPIO 48" は別物 (TP48 ↔ GPIO 47 がペア、TP47 ↔ GPIO 48 がペア)。番号が交差するので識別ミスに注意。

ESP32-P4 GPIO 47/48 を選んだ根拠:
- Waveshare 3.4C の 40 ピン拡張ヘッダ右列で**物理的に隣接**(配線楽)
- BSP (LCD/Touch/I2S/SD) が使う GPIO (4,6-13,26,27,32,39-44,53) と衝突しない
- ESP32-P4 GPIO matrix で UART1 を任意 GPIO に割当可能

備考:
- 以前 Phase 1 で「曲がっていた」TP20 / TP81-87 は SR150 SPI ブレークアウト用 (Path B 想定)、**TP47/TP48 とは別位置で健在**
- baud = 3 Mbps、QN9090 側は ANSI 色付き ASCII で出力
- TP47 への送信は Phase 2 後段 (制御プロトコル) で必要、Phase 2 初回は RX のみで OK
- SWD ピン (TP40/TP41) は QN9090 デバッグ用、ISP_ENTRY (TP36) は dk6prog 書込時のリセット用

---

### Phase 0: 環境準備 + 校正値バックアップ 【5/11-12】 (大半済)

**目的**: Path C の安全マージン確保。失敗時に元の Murata プリビルド FW に戻せる準備。

**タスク**

1. NXP MyAccount 登録 (まだなら)
2. NXP UWBIOT SDK ダウンロード (SR150 v04.06.00 推奨)
3. MCUXpresso IDE インストール (QN9090 開発用)
4. MCU-Link Pro のドライバ確認、PC で認識
5. **2BP/2DK 各 EVK の QN9090 フラッシュ全領域をダンプ**
   - `LinkServer flash -p QN9030 read 0x00000000 0x80000 backup_<EVK名>_qn9090.bin`
   - 校正領域 (IFR) も別途ダンプ
   - ダンプファイルは `firmware/2bp-config/firmware-backups/` (gitignore) に保管
6. EA-WO1391-1228 の正体確認 (実物見て M.2 か等)

**成果物**: `firmware-backups/2bp.bin`, `2dk_1.bin`, `2dk_2.bin`

**詰まりポイント**: NXP MyAccount は登録に時間かかることあり、早めに着手

### Phase 1: QN9090 で Murata サンプル動作確認 【5/5-12】

**目的**: NXP SDK でビルド・書込・動作確認のサイクルを確立。

**タスク**

1. NXP UWBIOT SDK の `demos/SR1XX/demo_ranging_controller` をビルド
2. Murata 提供のパッチ (`2bp_prebuilt_*.patch`) を適用
3. MCU-Link Pro 経由で 2BP に焼く
4. PC で UART モニタしながら Initiator 動作確認 (ペアの 2DK は出荷時 FW のまま)
5. 同様に 2DK に Responder ベースのサンプルを焼く試行 (Initiator サンプルを改造)

**成果物**: 自分でビルドした FW で 1:1 ranging が動く

### Phase 2: カスタム ASCII プロトコル実装 【5/12-19】

**目的**: ESP32 ↔ 2BP の自前 UART プロトコル定義・実装。

**タスク**

1. `firmware/2bp-fw/` にプロジェクト雛形作成
2. ASCII コマンド仕様策定 (`docs/2bp-protocol.md` 確定):
   - `RANGE` → `OK TAG1:dist,az,el TAG2:dist,az,el ...`
   - `SET_TAGS <count> <mac1> <mac2> ...`
   - `STATUS` → `READY` / `BUSY` / `ERROR`
3. UART タスクと Ranging タスクを FreeRTOS で分離
4. round-robin スケジューラ (タグ N 個を順番に Unicast TWR)
5. ESP32 側 `main/uwb/uwb_uart.c` で ASCII パース実装
6. 1:1 で実距離・方位データが LVGL レーダーに乗る

**成果物**: ESP32 のレーダー画面に 1 タグの実距離が出る

### Phase 3: 2DK Responder 化 + 2 タグ同時 【5/19-26】

**目的**: 2 タグを round-robin で同時に追跡。

**タスク**

1. `firmware/2dk-fw/` で 2DK 用 Responder FW 実装
2. 2DK ×2 個を異なる UWB MAC で Responder として常駐
3. 2BP の round-robin スケジューラを 2 タグ対応化
4. ESP32 のレーダー画面に 2 タグの実位置が出る
5. ゲームロジック (30cm 以内 N秒で取得判定) の実装・チューニング

**成果物**: 2 タグを近づけたら順次「取得」アニメ → 星が増える

### Phase 4: 神龍演出 + ウーロン音声 + 7タグ演出 【5/26-6/10】

**目的**: 7 タグ揃った演出を仕上げる (実機 2 タグ + 5 タグぶん演出)。

**タスク**

1. VOICEVOX で WAV 出力:
   - shenron_appear.wav: 「神よ…願いを言え…」
   - oolong.wav: 「ギャルのパンティおくれーっ！」
   - shenron_grant.wav: 「よかろう…」
2. SD カードから WAV を I2S で再生
3. 神龍召喚アニメ (緑→金フェード + 雷 + 龍シルエット)
4. パンティ演出 (PNG が左右に揺れて降ってくる)
5. **「2 個実機取得 → 5 個ぶんは演出のみで足す」分岐ロジック** (動画用)
6. 起動から終了までの状態遷移を一通り通す

**成果物**: 「2 タグ取って → 神龍召喚 → ウーロン → 終了」が一気通貫で動く

### Phase 5: デモ動画撮影 + ProtoPedia 応募 【6/10-22】

**シナリオ**: 詳細は `docs/demo-scenario.md`

| 時間 | 内容 |
|---|---|
| 0:00-0:10 | タイトル: 「Dragon Radar UWB - DigiKey Make ONE Challenge 2026」 |
| 0:10-0:25 | ハード紹介: Murata 2BP/2DK、Waveshare 丸型 LCD のアップ |
| 0:25-0:40 | 「自分イチ」テーマ説明 |
| 0:40-1:20 | **公園で子供がタグ 2 個を探すデモ** (本物の UWB 動作) |
| 1:20-1:30 | カット繋ぎで「7 個目発見」演出 (内部で擬似的に 7 個揃える) |
| 1:30-1:45 | 神龍召喚 |
| 1:45-1:55 | ウーロン降臨「パンティおくれーっ」 |
| 1:55-2:00 | クレジット |

**応募内容**:
- ProtoPedia 一般公開で登録
- デモ動画 URL (YouTube 限定公開可)
- myLists 部品表 URL
- 「自分イチ」テーマ:
  - 候補: 「自分イチ初の UWB 統合」「自分イチ初の MCUXpresso ファーム開発」「自分イチ初の二段 MCU 構成 (ESP32 ↔ QN9090) 通信設計」
- 使用パーツ全 SKU、開発過程の写真、GitHub リンク (MIT or Apache-2.0)

### Phase 6: Path B 移植チャレンジ 【7-8月、応募後】

**目的**: ESP32 で SR150 を SPI 直叩きできるようにする (Maker Faire 用「進化版」)。

**タスク**

1. NXP UWBIOT SDK の HAL 層 (SPI transport, GPIO, timer) を ESP-IDF に移植
2. UCI core を ESP32 上で動作確認
3. 校正値を `UWB_DeviceConfig_SR1XX.h` から移植
4. 既存の Path C 実装と切替可能に (config flag で選択)

### Phase 7: 7 タグ拡張 + Maker Faire 出展 【7-9月】

**タスク**

1. 6/22 応募後すぐ 2DK ×5 を DigiKey に発注
2. 5 個ぶんの 2DK に Responder FW 焼込
3. round-robin スケジューラを 7 タグ対応化、サイクル時間チューニング
4. (オプション) 自作タグ PCB 設計・試作
5. Maker Faire Tokyo 2026 (2026-09-05/06) で 7 タグ完全版を実演

---

## 依存関係

### ESP32-S3 側 (ESP-IDF)

- ESP-IDF v5.3.2 ✅ インストール済 (`~/esp/esp-idf`)
- LVGL v9.2 ✅ managed component で取得済
- ST77916 LCD driver (Waveshare 公式 GitHub から取込予定)
- esp_lcd_touch_cst816s ✅ managed component で取得済
- esp_audio or esp-adf (WAV 再生)
- FATFS (SD カードアクセス)

### QN9090 側 (Path C で新設)

- MCUXpresso IDE
- NXP UWBIOT SDK SR150 v04.06.00 + Murata パッチ
- LinkServer (MCU-Link Pro と通信)

### ホスト側ツール

- VOICEVOX - 音声生成
- ffmpeg - 動画編集 + WAV 変換
- LVGL Image Converter - PNG→C 配列
- DaVinci Resolve / CapCut - 動画編集

---

## トラブルシューティングメモ

| 症状 | 対処 |
|---|---|
| QN9090 認識されない | MCU-Link Pro のファーム最新化、SWD ピン位置確認、Target Power 設定 |
| カスタム FW 焼いた後動かない | `firmware-backups/` から元の Murata FW を復元 |
| LCD が真っ黒 | backlight GPIO HIGH 確認、SPI clock を 10MHz まで下げる、PSRAM 有効化確認 |
| LVGL がカクつく | `LV_COLOR_DEPTH=16`、PSRAM 有効化、frame buffer を internal RAM に |
| UART 文字化け | ボーレート再確認、GND 共通確認、配線長を 10cm 以内に |
| AoA がフラフラ | 移動平均 window を 10 まで増やす、屋外で撮影 |
| WAV が再生されない | I2S ピン番号確認、サンプルレート 16kHz / 16bit / mono か確認 |
| ranging のレートが低い | round-robin の各 TWR を高速化 (UCI session を維持したまま target 切替) |

---

## 重要な制約と判断記録

### Murata FW のロール制約 (重要)

- **2DK の出荷時 FW は Initiator/Controller 固定**。タグ (Responder) として使うにはカスタム FW 必須。
- 2BP は出荷時 FW で Initiator/Responder 両対応だが、PnP モードは Unicast 1:1 のみ。

### サンプルスクリプトはすべて Unicast

Murata 提供の Python スクリプトは `*_Unicast_*.py` のみ。1:N (Multicast) TWR は SDK 側でサポートされているが、サンプルは未提供。Phase 2-3 で round-robin Unicast を自前実装する。

### 2BP 1 個運用のリスクと対策

- 2BP は ~$150 と高価、保有 1 個のみ
- Path C 採用により破壊的操作 (QN9090 erase など) は不要
- それでも Phase 0 で必ず QN9090 フラッシュをバックアップ
- カスタム FW 開発中は MCU-Link Pro 経由で何度でも書き戻し可能

### EA-WO1391-1228 の扱い

- 正体未確定 (Embedded Artists 系の M.2 系モジュール推定)
- Phase 0 で確認、用途が判明したら本仕様書に追記

---

## Claude Code への指示

1. Phase 0 から順番に着手。各 Phase 完了後に成果物を確認してから次へ進む。
2. 各タスクは git commit を細かく切る (Phase ごとに最低 3 コミット)。
3. 完了したタスクはチェックボックスにチェックを入れる。
4. 詰まったら作業をブロックして人間に質問する (推測で進めない)。
5. ESP-IDF / MCUXpresso のビルドエラーは抱え込まずに即報告。
6. ハードウェアに依存する確認 (LCD 表示、UART 受信、QN9090 書込、UWB 動作) は人間が実機で確認、結果をフィードバック。
7. NXP UWBIOT SDK の中身は NDA 配下、コミット禁止 (`firmware/2bp-config/` は gitignore 済)。
8. **Path B 移植は 6/22 応募完了後に着手** (それまでは Path C に集中)。

開発開始日: 2026-04-29
GW 残り集中期間: 5/3 (日) - 5/4 (月)
コンテスト応募締切: **2026-06-22**
Path B 移植開始: 2026-07 (応募後)
Maker Faire Tokyo 2026: 2026-09-05/06

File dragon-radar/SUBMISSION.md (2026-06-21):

# ProtoPedia 応募 下書き ─ ドラゴンレーダー（DigiKey Make ONE Challenge）

各フィールドにそのままコピペできるよう整理しています。`【TODO】` は実物（写真・動画）が要る箇所。

---

## 作品ステータス
**完成**（端から端まで動作するデモあり。可搬電源のみ今後）

## 作品タイトル（50文字まで）
```
ドラゴンレーダー ─ UWBで“ドラゴンボール”を本当に探す（一星球）
```

## 作品のURL
```
https://github.com/Ryujiyasu/dragon-radar
```

## 概要（100文字以内）
```
漫画のドラゴンレーダーを実機化。UWB測距とIMUで樹脂製“一星球”の距離と方向を丸型ディスプレイにリアルタイム表示。端末を回しても光点は実方向に張り付く。
```

## ライセンス
**表示する：CC BY 4.0+**（推奨）

---

## 画像（5枚／1枚目=メイン, 推奨880x495）
1. 【TODO】完成レーダー本体＋一星球（メイン映え）
2. 【TODO】測距中の画面（光点＋距離・方位）
3. 【TODO】樹脂の一星球（かえんオレンジ＋★）
4. 【TODO】内部（ESP32-P4＋2BP＋IMU＋配線）
5. 【TODO】システム構成図

## 動画（YouTube/Vimeo）
```
【TODO】デモ動画URL（①距離・方位が出る ②端末を回しても光点固定 ③ボタンでレンジ切替 を1本に）
```

---

## システム構成（どう作ったか）

```
[ドラゴンボール(樹脂) 内: UWBタグ 2DK / CR2032]
        ⇅  UWB 双方向測距(DS-TWR・到来角AoA)
[レーダー本体: UWB 2BP(SR150)]
        │ 距離・方位・仰角
        ▼ UART 3Mbps
   [ESP32-P4] ──LVGL──► 丸型LCDに光点(blip)
       ▲                    ▲
  BNO086 IMU(方位補正)   ボタン(レンジ1m/3m/10m)
```

1. ドラゴンボール内の**UWBタグ(Murata Type2DK / SR040)**と、レーダー側の**UWB(Type2BP / SR150)**が双方向測距(DS-TWR)し、**距離＋到来角(AoA)**を取得（UCIバージョンを1.31に整合させるのが成立の鍵）。
2. 測距結果を**UART(3Mbps)でESP32-P4へ**。**LVGL**で丸型LCDに光点描画。
3. **BNO086(IMU)**で端末方位を取り、UWBの相対角を**ワールド座標へ補正**→回しても光点が実方向に固定。
4. 前面**ボタン(GPIO22)**で表示レンジを**1m→3m→10m**切替（原作のズーム）。
5. 筐体は**OpenSCADでパラメトリック設計→Bambu A1(PLA)**、ドラゴンボールは**OpenSCAD→AnyCubic Photon M3(水洗いレジン/かえんオレンジ)**で印刷。

> 構成図画像：**`docs/system-diagram.png`（880×495・作成済）** を登録。編集は `docs/system-diagram.dot` → `dot -Tpng`。

## 開発素材（候補から選択）
`ESP32`／`ESP-IDF`／`LVGL`／`FreeRTOS`／`OpenSCAD`／`UWB`／`BNO086`
（Murata Type2BP/Type2DK・NXP SR150/SR040・AnyCubic Photon M3 も本文で言及）

## タグ（5個程度）
`UWB`／`ドラゴンボール`／`ESP32-P4`／`3Dプリント`／`測距/AoA`／`IMU`

---

## ストーリー

### きっかけ
子どもの頃に憧れた**ドラゴンレーダー**。「それっぽい見た目」ではなく、**実際に電波で測距して本当に探せる**ものを作りたかった。Make **ONE** Challenge にちなみ、探す球は **一星球（★1）** に決めました。

### 何ができるか
手に持った丸いレーダーが、樹脂製“ドラゴンボール”の**方向と距離をリアルタイムに指します**。ボールの中には**UWBタグ**が入っていて、レーダー本体が超広帯域無線で**距離**と**到来角(AoA)**を測定。**端末を回しても光点は実方向に張り付き**、ボタンで**探索レンジを拡大/縮小**できます ── 原作の挙動そのもの。

### 技術的こだわり
- **本物の測距**：Type2BP(SR150)↔Type2DK(SR040)で双方向測距。UCIバージョンを**1.31に揃える**ことで成立。
- **回してもブレない方位**：UWBのAoAは端末基準の相対角。**BNO086(IMU)**でワールド座標へ補正し、原作のように光点が実方向へ固定。
- **丸型ディスプレイ＋LVGL**：ESP32-P4で受信・平滑化・描画。ボタンでレンジズーム。
- **物理クラフト**：筐体はFDM、ドラゴンボールは**水洗いレジン（かえんオレンジ）**で“ガラス玉”の質感。星は彫り込み→赤で差し塗り。

### 苦労した点
1. **UCIバージョン整合**で初めて測距成立。
2. 起動時の無線チップFW転送が**ループ**→完全電源OFF/ONでクリア。
3. タグ2個のうち**1個が個体不良**（無線チップがアプリ段で起動せず）。もう1個で開通 ── 結果、**“ONE＝一星球”**という答えに繋がった。
4. **ヘッドレス製造**：FDMはBambu A1を**LAN越しに無人スライス＆印刷**（OrcaSlicer CLI＋MQTT/FTPS）。樹脂は**CLIスライサが無い**ため **OpenSCAD→PrusaSlicer CLI→UVtools** で `.pm3` を自作生成しPhoton M3で印刷。

### 電源の現状
ドラゴンボール内の**タグはCR2032コイン電池で自立**＝球は完全ワイヤレス。レーダー本体は**USB給電**（モバイルバッテリーで可搬化、製品版はLiPo＋充電/昇圧内蔵が次の一手）。

### 今後
レーダー本体の電源内蔵 ／ 7星すべての収集モード ／ 複数タグ同時測距 ／ 独自QN9090ファームでの小型化。

### Wow メッセージ
**フィクションの“あの丸いレーダー”が、電波で本当にドラゴンボールを指した瞬間。** 画面の光点が、机の向こうの一星球へぴたりと向いたとき ── 子どもの頃の憧れが、現実の測距技術で動き出しました。

---

## メンバー
- **Ryuji Yasukochi（@ryujiyasu）** ／ 役割例: `企画・回路/配線` `ファームウェア(ESP32-P4/UWB/IMU)` `3D設計・製造`

## 関連リンク
```
https://yasu-home.com/dragon-radar-uwb-imu-ranging/
https://github.com/Ryujiyasu/dragon-radar
```

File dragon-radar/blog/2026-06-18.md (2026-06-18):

---
title: "壊れたタグ、ファーム転送ループ、そして一星球 ─ ドラゴンレーダー開発記 6/18"
date: 2026-06-18
tags: [DigiKey Make ONE Challenge, UWB, Murata Type2BP, Type2DK, ESP32-P4, BNO086, ドラゴンレーダー]
---

# 壊れたタグ、ファーム転送ループ、そして一星球 ─ ドラゴンレーダー開発記 6/18

DigiKey Make ONE Challenge に向けて作っている「ドラゴンレーダー」。UWB（超広帯域無線）で“ドラゴンボール”の方向と距離を探す、あの円い装置の実物化です。今日はついに**本物の測距を通す**のが目標でした。結論から言うと──通りました。ただしそこに至るまでが、まあ濃かった。

## 第一幕：沈黙する2BP、ファーム転送の無限ループ

まず親機側（Murata Type2BP / NXP SR150）が測距ストリームを吐かない。ログを覗くと、起動のたびに無線チップへファームを転送する処理が延々ループして、肝心の測距処理にたどり着かない。チップへの問い合わせだけが回り続ける。

CBUSのリセット極性をいくつも試し、最後に効いたのは拍子抜けするほど物理的な一手──**USBを全部抜いての完全電源OFF→ON**。無線チップのスタック状態がクリアされ、次の瞬間：

```
（無線チップから測距データの受信ログが連続で流れ出す）
```

3Mbpsで測距ストリームが流れ出しました。ここで一息。

## 第二幕：「相手がいない」だけだった

P4（ESP32-P4＋丸型LCD）側は配線も受信もOK。なのにレーダーは無反応。原因は単純で、**測距の相手＝2DKタグがまだ応答していなかった**から。親機は「相手なし（FFFF）」を律儀に送り続けていただけでした。整形済みの `RADAR,…` 行は、有効な測距が成立した瞬間にだけ出る設計。つまり、タグを起こせばいい。

## 第三幕：タグが、1個、死んでいた

ここが今日いちばんの泥沼。タグ#1にControleeファームを焼く → 無線チップへのファーム転送は完走するのに、その後**初期化がタイムアウト（チップが応答しない）**で無限リトライ。完全電源サイクルでもダメ。最後に純正factoryファームまで戻して切り分けたところ──**factoryでも起動しない**。

> ブートローダは生きている（FW転送はできる）のに、アプリ段で無線チップが目を覚まさない。これはソフトじゃない、**この個体のハード不良**。

2個あるタグの片方が、静かに壊れていました。

## 第四幕：そして、探した

気を取り直してタグ#2へ。同じ手順でControleeを焼いて起動した瞬間：

```
dragon-radar: tag=1 d=651 mm az=-19 el=5
dragon-radar: tag=1 d=650 mm az=-19 el=4
```

**距離65cm、方位−19°。** 机の上の実際の位置そのものでした。タグ → 親機 → 有線 → P4 → 円いレーダー画面の光点（blip）まで、端から端まで一本につながった瞬間です。長かった。

<!-- TODO: ここに実機写真を差し込む。例: ![測距が通った瞬間の実機](./img/2026-06-18-ranging.jpg) -->

## 一星球という答え

タグが2個必要なら2個作る、と思っていたドラゴンボール。でも動くタグは1個。そして大会の名は **Make “ONE” Challenge**。

……**一星球（★1個）**にしよう、と即決まりました。制約が、いちばんきれいな答えを連れてきた感覚。設計を star=1 に確定して出力。

## おまけが本気になった：IMUを入れた

「ついでにIMUも効いてる？」から始まって、結局その場で本実装。BNO086のSHTP/SH-2ドライバを書き、タッチパネルと同じI2Cバスに相乗りさせて方位（heading）を50Hzで取得。UWBの「端末基準の角度」を方位で世界座標に補正することで、**端末を回しても光点が実方向に張り付く**ようにしました。

```
imu_bno086: heading=-0.7 ok=1 samples=42206
```

## 今日の到達点

- 📡 2BP ↔ 2DK 実UWB測距（距離・方位・仰角）
- 🧭 BNO086で方位補正（回しても実方向）
- 🟠 一星球を確定・STL出力
- 🖥 丸型LCDに光点表示

壊れたタグに半日溶かしたけれど、「実際に探せるドラゴンレーダー」がこの手の中で動いています。次は樹脂で一星球を刷って、タグを封じ込める番。

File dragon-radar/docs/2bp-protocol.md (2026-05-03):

# 2BP ↔ ESP32 ASCII プロトコル仕様 (Path C)

ESP32-S3 と 2BP の QN9090 (カスタム FW) が UART 経由でやり取りする自前プロトコルの定義。

## 物理層

- **接続**: 2BP の USB-C (FTDI FT230XQ 経由 USB-CDC) → ESP32-S3 の USB ホスト or 直接 UART
- **想定ボーレート**: 115200 8N1 (Phase 1 で確定)
- **フロー制御**: なし

### 配線パターン (どちらか選択)

#### A) USB-CDC 経由 (推奨、ハード改造不要)
```
2BP USB-C ── USB ケーブル ── ESP32-S3 USB OTG (Host モード)
                              └─ esp_usb_host_cdc_acm で FTDI を喰う
```

#### B) 直 UART (USB が不安定なら)
```
2BP のヘッダ (UART_TX/RX) ── ESP32 GPIO (UART2)
※ ピン位置は QN9090 のサンプル FW のシリアル出力ピンを参照、Phase 1 で確定
```

## アプリケーション層 (ASCII コマンド)

行ベース、`\r\n` 区切り。コマンドは ESP32 → 2BP、レスポンスは 2BP → ESP32。

### コマンド一覧

| コマンド | 意味 | レスポンス例 |
|---|---|---|
| `RANGE\r\n` | 1 サイクル分の round-robin ranging を即時実行 | `OK TAG1:1234,30,-5 TAG2:2100,-15,40\r\n` |
| `START <interval_ms>\r\n` | 指定間隔で連続 ranging 開始 (例: `START 33`) | `OK\r\n` その後定期的に `RANGE_RESULT TAG1:...\r\n` |
| `STOP\r\n` | 連続 ranging 停止 | `OK\r\n` |
| `SET_TAGS <count> <mac1> <mac2> ...\r\n` | 追跡対象タグの UWB MAC を登録 | `OK\r\n` |
| `STATUS\r\n` | 現在状態を返す | `READY` / `RANGING` / `ERROR <code>` |
| `RESET\r\n` | QN9090 ソフトリセット | `OK\r\n` (リセット後再 init) |
| `VER\r\n` | カスタム FW のバージョン取得 | `VERSION 1.0.0 SDK 4.6.0\r\n` |

### レスポンス形式

#### 成功
```
OK [<key1>:<val1> <key2>:<val2> ...]\r\n
```

#### Ranging 結果 (TAG_n の値は CSV)
```
TAG<id>:<distance_mm>,<azimuth_deg>,<elevation_deg>[,<rssi>][,<flags>]
```
- `distance_mm`: 0-65535
- `azimuth_deg`: -180 〜 +180 (整数 deg、または -1800〜1800 で 0.1deg 精度)
- `elevation_deg`: -90 〜 +90
- `rssi`: 任意 (Phase 2 で必要なら追加)
- `flags`: 任意 (e.g. `LOS=1`, `FOM=100`)

#### エラー
```
ERROR <code> <message>\r\n
```
| code | 意味 |
|---|---|
| `NO_TAG` | 指定タグから応答無し |
| `BUSY` | 別操作中 |
| `BAD_CMD` | コマンドパース失敗 |
| `RF_FAIL` | UCI レイヤエラー |

### 通信例

```
# ESP32 起動時
ESP32: VER\r\n
2BP : VERSION 1.0.0 SDK 4.6.0\r\n

# タグ登録
ESP32: SET_TAGS 2 ABCD1234 ABCD5678\r\n
2BP : OK\r\n

# 1 サイクル要求
ESP32: RANGE\r\n
2BP : OK TAG1:1234,30,-5,FOM=100 TAG2:2100,-15,40,FOM=85\r\n

# 連続モード開始
ESP32: START 33\r\n
2BP : OK\r\n
2BP : RANGE_RESULT TAG1:1240,32,-6,FOM=100 TAG2:2098,-14,41,FOM=88\r\n
2BP : RANGE_RESULT TAG1:1235,31,-5,FOM=100 TAG2:NO_RESPONSE\r\n
ESP32: STOP\r\n
2BP : OK\r\n
```

## QN9090 側の実装方針

- FreeRTOS タスク 2 個:
  - **UART タスク**: stdin から 1 行読んでコマンドキューへ enqueue
  - **Ranging タスク**: コマンドキューを読んで NXP UCI Host stack を駆動
- round-robin: 設定済みタグを順に Unicast TWR、結果をまとめて 1 行で返却
- 1 タグあたり TWR 約 10ms 想定 (要実測)、2 タグで 20ms、7 タグで 70ms 程度
- ESP32 側のフレームレート (LVGL 30Hz = 33ms) に合わせるなら 7 タグはギリギリ

## ESP32 側の実装方針

- `main/uwb/uwb_uart.c`: 上記レスポンスのパーサ
- 結果を `uwb_measurement_t` 構造体に詰めて FreeRTOS queue へ
- LVGL タスクは queue から最新値を読んでレーダー描画

## Phase ごとの実装ステップ

| Phase | 範囲 |
|---|---|
| Phase 1 | 出荷時 FW で raw UCI を眺めるだけ (このプロトコルは未使用) |
| Phase 2 | 2BP に最小カスタム FW、`VER` `STATUS` `RANGE` (1 タグ) を実装 |
| Phase 3 | `SET_TAGS` `START`/`STOP`、2 タグ round-robin |
| Phase 7 | 7 タグ拡張、サイクル時間チューニング |

## 参考にする Murata ドキュメント

`firmware/2bp-config/docs/` 配下 (NDA):
- Type 2BP Evaluation Board Quick Start Guide_EVK_Rev4.2.pdf
- Type 2BP UWB Module EVK with Raspberry Pi4 Linux_RevD.pdf (UART 接続例)
- SR150_UCI_Specification_v1.23_Murata.pdf (UCI フレーム形式)
- Type 2BP EVK Enabling AoA Setting_RevC.pdf (AoA 校正)

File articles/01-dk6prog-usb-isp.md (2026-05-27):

# dk6prog (SPSDK) で QN9090 を USB ISP だけで焼く

## 要約

NXP QN9090 を載せた評価ボード (Murata Type 2BP EVK / 2DK EVK 等) のファームを書き換えるとき、SWD (J-Link / MCU-Link Pro) が標準ルートとされるが、ボードのデバッグピンが折れていたり配線できない事情があるとそこで詰まる。

そこで便利なのが **SPSDK** に含まれる `dk6prog` という Python ツールで、USB ケーブル 1 本だけで ISP (In-System Programming) モードに入って書き換えできる。

本記事では Linux 上で `pip install spsdk` だけで導入して、QN9090 のフラッシュ全領域を吸い出してバックアップ → カスタムファームを書き込む手順を 1 枚にまとめる。

## なぜこれが効くか

QN9090 (および兄弟の DK6 シリーズ) は ROM ブートローダに ISP モードを備えていて、特定ピン (PIO_5 / ISP_ENTRY) を引いた状態でリセットすると UART 経由でフラッシュ操作を受け付ける。Murata / NXP の DK6 EVK はオンボードに FTDI FT230X USB-UART ブリッジが載っていて、USB ケーブル 1 本でこの UART に到達できる。

SWD で書ける環境を持っていない人 (J-Link を持っていない、MCU-Link Pro が手元にない、開発端末が Windows 縛りで動かないなど) でも、**Python が動けば書ける**のが大きい。

## 手順

### 0. 前提

- 開発端末: Ubuntu 24.04 (Linux 一般、macOS でも同様)
- ターゲット: NXP QN9090 ベースの DK6 EVK (例: Murata Type 2BP / 2DK)
- USB ケーブル (データ通信対応 micro-USB、充電専用品はダメ)

### 1. SPSDK をインストール

```bash
pip install spsdk pyftdi
```

(venv 推奨。SPSDK は依存が多めなので素の Python に入れると他プロジェクトと衝突しやすい。)

### 2. USB 接続して認識を確認

EVK と PC を USB でつないだ状態で:

```bash
dk6prog listdev
```

```
List of available devices:
DEVICE ID: DM86TTWC, VID: 0x403, PID: 0x6015, ...
```

`DEVICE ID` がそのまま `-d` の引数になる。Murata 出荷品は全 EVK で同じシリアルが振られていることがあり、複数挿していると後続コマンドで衝突するので、**作業時は対象 1 個だけ挿す**。

### 3. ISP モードに入れて疎通確認

EVK の **ISP ボタン (PIO_5 / ISP_ENTRY) を押しながら RESET を離す**と ISP モードに入る (ボードによっては「ISP」シルク印刷がある専用ボタン、ない場合は基板上のテストパッドを GND に落とす)。

```bash
dk6prog -d DM86TTWC info
```

```
Chip ID: 0x88888888
ROM Version: 0x140000cc

  Memory   Memory ID   Base Address   Length    Sector Size
----------------------------------------------------------------
  FLASH    0           0x0            0x9de00   0x200
  PSECT    1           0x0            0x1e0     0x10
  ...
```

`info` が返ってくれば疎通 OK。

### 4. 焼く前に「出荷時 FW」をバックアップする

これが本記事で一番伝えたい部分。Murata の EVK は出荷時にメーカー校正済の FW が入っており、これを潰すと TX パワーや水晶発振の校正が失われる。

```bash
dk6prog -d DM86TTWC read 0 0x9DE00 -o factory_backup.bin
```

`0x9DE00` (約 632KB) が FLASH 全長。1 度だけ取って、git に上げる代わりに「火事から助かる」場所に保管しておくと心理的に強い。

### 5. カスタムファームを書き込む

```bash
dk6prog -d DM86TTWC erase 0 0x9DE00
dk6prog -d DM86TTWC write 0 my_custom_fw.bin
```

(erase は `write` の中で勝手にやってくれる版もあるが、明示的に erase してから write する方が事故が少ない。)

### 6. 復旧したいとき

```bash
dk6prog -d DM86TTWC erase 0 0x9DE00
dk6prog -d DM86TTWC write 0 factory_backup.bin
```

これで step 0 の状態に戻る。安心。

## ハマりどころメモ

| 症状 | 原因 / 回避 |
|---|---|
| `2 USB devices match URL` | 同じシリアルの EVK が複数挿さっている。物理的に片方を抜く |
| `no langid permission issue` | pyftdi backend は libusb で root 権限要求することがある → `sudo -E` で実行 (環境変数を保持しないと PATH が消えるので `-E` 必須) |
| `Failed to enter ISP mode` | ISP ボタン押しが遅い / 早い。USB を抜いてボタン押しっぱなしで挿し直す → リセットボタンも併用 |
| `Chip ID: 0x88888888` のまま | これは正常 (ISP モードで MAC アドレスが返らない仕様) |

## 何が良くなったか

- **SWD ハードが要らない** (J-Link / MCU-Link Pro は 1 台 1〜2 万円)
- **OS を選ばない** (Windows 限定の DK6Programmer.exe に縛られない)
- **CI に組み込める** (シェルから叩けるので、ビルド → 焼き → テスト を一筆書きできる)

「SWD ピンが曲がってた」「IDE のドライバが入らない」みたいな ハードウェアやアーキテクチャに本質的でない問題で停滞している人にとって、`dk6prog` 経由のフラッシュは数時間〜数日を取り戻すポテンシャルがある。

## 参考

- [NXP SPSDK GitHub](https://github.com/nxp-mcuxpresso/spsdk)
- DK6 ファミリ User Manual (NXP)

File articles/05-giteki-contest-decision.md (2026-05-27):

# 技適未確認の WiFi ボードを国内コンテストに出すなら何を捨てるか

## 要約

中国メーカーから個人輸入した ESP32 系ボード (含む WiFi6 モジュール) を、**国内のメイカーコンテストに展示**することを考えるとき、最初にチェックすべきは「**そのボード上の無線モジュールに技適マークがあるか**」。

技適マーク (Telec) は電波法に基づく型式認定で、これ無しの無線機を電波を出す状態で国内使用すると電波法違反になる。**特例制度 (180 日試験運用) はあるが、公開イベント常時運用には合わない**。

技適未確認ボードを「使うかどうか」を悩むのではなく、**技適なしを前提にハードウェアアーキテクチャを設計し直す**のが正しい意思決定。本記事ではその意思決定を最近実例ベースで整理する。

## 何が問題なのか

ESP32 系ボード、特に **「ESP32-P4 + ESP32-C6 (WiFi6 コンパニオン)」を組み合わせた製品**は、Espressif 単体モジュールでは技適済の variant があるが、**第三者メーカーが基板に載せて組み立てた完成品**は技適マーク (基板上のシールド表面に `R 003-XXXXXX` の刻印) がそのまま継承されないことが多い。

具体例:

- Espressif の `ESP32-C6-WROOM-1` モジュールには技適済 SKU が存在する
- ところが Waveshare 系の「ESP32-P4-WIFI6-Touch-LCD-XC」のような完成品ボードに載っている ESP32-C6 が、技適済 SKU を使っているとは限らない
- ボード上のシールドに R 番号が刻印されているか目視確認するしか手段がない

筆者の手元の Waveshare ESP32-P4-WIFI6-Touch-LCD-3.4C は **目視で技適マーク確認できず**だった。

## 電波法の建付け

総務省の電波法では、技適マーク (技術基準適合証明、特定無線設備の技術基準適合認定) 未取得の無線設備を国内で電波を発射する状態で使用すると違反となる (第 4 条 / 第 38 条系)。

ただし救済として **電波法第 4 条の 2 に基づく「実験等無線局」/「特例制度」** があり、開発・実験目的に限り 180 日間届出ベースで使用できる枠が用意されている。

**ただし** これは「自宅・自社の閉じた環境で開発する」想定の制度で、

- 公開イベント (Maker Faire、コンテスト出展、商業展示) で「常時動いている」状態は実験運用とみなされにくい
- 違反扱いになると刑事罰 (1 年以下の懲役または 100 万円以下の罰金) の可能性がある
- 主催者側 (大型イベントは大概スタッフが電波法を理解している) から会場ルールでも止められる

**「コンテストに出す」という目的なら、特例制度を当てにせず WiFi/BT を最初から使わない設計にする**のが現実解。

## 設計上の意思決定

筆者の場合は ESP32-P4 系ボードを LCD ホストとして使う前提があり、「ボード上の WiFi/BT を一切初期化せず、有線通信に切り替える」設計を採用した。

具体的に何を犠牲にして何を残したか:

| 機能 | 当初の構想 | 技適なし前提後 |
|---|---|---|
| 無線測距 (UWB) | UWB チップ (Murata SR150/SR040) で実装 | 同じ (UWB は別途技適済モジュールを使用) |
| デバッグログ転送 | WiFi で開発端末に飛ばす | USB シリアルのみ |
| センサノードとの通信 | BLE / WiFi で散発接続 | 物理 UART 配線 |
| OTA ファーム更新 | WiFi 経由 | SD カード差し替え / USB |
| Web 設定 UI | スマホブラウザから WiFi 経由 | LCD タッチ UI のみ |

「**物理配線で全部やる**」と決めると、設計はむしろシンプルになる。ペアリング・認証・電波輻射の干渉考慮が消える。

## チェックリスト: 自分のボードで何を確認すべきか

国内コンテスト用に中華製評価ボードを選ぶときは以下を順に:

1. **基板上の無線モジュール (銀色シールド) 表面に技適マーク or `R 003-XXXXXX` の刻印**があるか目視
2. メーカー商品ページに「Japan / 技適 / Japanese certification」明示があるか
3. 国内代理店経由なら、その代理店が技適済バージョンとして売っているか
4. どれもダメなら → **そのボードの WiFi/BT は使わない設計**にするか、技適済の別ボード (ESP32-DevKitC-32E など) に置き換える

技適済 ESP32 系の入手:

- 国内代理店 (秋月電子、スイッチサイエンス、マルツ等) から正規流通品を買えば技適マーク済 (`R 003-XXXXXX` 刻印あり)
- AliExpress / Taobao から個人輸入したものは大概グレー

## まとめ

- **公開イベント展示が前提なら、WiFi/BT を使う設計を最初から避ける**のが安全
- 技適マークの有無は **ボード本体ではなく、基板上の無線モジュールのシールドに刻印**されているかで判断
- ハードウェア構成を「技適なしを前提に再設計」する方が、特例制度を当てにするより早くて確実
- 開発生産性的にも、有線通信に絞ると **ペアリング・認証・電波干渉が消えてシンプルになる**ことが多い

最近の組込デバイスは「WiFi/BT が付いてるのがデフォルト」になっていて、それを使わない設計を最初から組むのは少し勇気がいるが、**コンテスト出展という目的を考えると、技適まわりは設計上の制約ではなく前提として扱う**べき項目。

電波法は古い法律だが、まだ生きている。

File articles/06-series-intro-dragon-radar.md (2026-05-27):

# 連載 #0 ドラゴンレーダーを真面目に作る

## 何を作るか

ドラゴンボールに出てくる「ドラゴンレーダー」を、**現代の UWB (Ultra-Wide Band) 測距技術で本当に動くハードウェアとして作る**。

具体的に:

- プレイヤーが持つ円形 LCD 端末に、周囲のドラゴンボールが**距離と方向と共に**表示される
- ドラゴンボール側は小型タグ (UWB トランスポンダ) で、複数個 (理想は 7 個) を会場に散らせる
- LCD は玩具版ドラゴンレーダー (1980 年代バンダイ) の画面をオマージュした緑グリッド + コーラル三角ポインタ + ゴールド光点
- 押せばボタン音、近づけば効果音 (SE)、見つけたら BGM

これを **DigiKey Make ONE Challenge 2026 (応募締切 2026-06-22)** に出展、その後 9 月の Maker Faire Tokyo にデモ持ち込みする計画で動いている。

## なぜ UWB か

ドラゴンレーダー作品は過去にもファンメイドで何度か試みられているが、ほぼ全て **GPS** か **BLE RSSI** か **画像認識** ベースで作られていて、

- GPS は屋内で精度が出ない、しかも数 m 単位の誤差
- BLE RSSI は壁 1 枚で値が乱れる、向き判定不可
- 画像認識はカメラ視野内しか見えない、隠されたら終わり

「**5 cm 精度で距離が分かる、向きも 1〜2° で分かる、見通し外でも壁 1 枚なら抜ける**」という条件を満たすのは **UWB が唯一の現実解**。スマホ (iPhone 11 以降、Pixel 6 Pro 等) にも入っている技術で、AirTag が「家具の裏のものを正確に指し示す」のはこれ。

ハード的には NXP の SR150 (ホスト + AoA 対応) と SR040 (タグ専用、超低消費電力) を採用する。Murata から評価ボード (Type 2BP / Type 2DK) が出ていて、国内技適も取られている。

## なぜバンダイ風 UI か

「Apple Find My っぽい現代的な UI」も検討したが、面白くない。

ドラゴンレーダーは 1984 年に玩具として実物が存在する (バンダイ商品)。緑の LCD に緑のドット、ゴールドの数字、コーラル色の三角ポインタ、円形フィルムを回すスイープ。**子供だった世代が大人になった今でも、この画面を見せると「あっ」となる**。

技術が当時のフィクションに追いついた瞬間を、**当時のビジュアル言語のまま**届ける。これが本作品のテーゼ。

## 構成の全体像

```
[ プレイヤー手持ち端末 ]
  ESP32-P4 (RISC-V 400MHz, PSRAM 32MB)
    + 800x800 円形 IPS LCD (Waveshare 3.4C)
    + LVGL 9 (Bandai 風レーダー UI)
    + microSD (BGM/SE/ボイス)
    + I2S Codec ES8311 + スピーカー
    +─[UART 3Mbps 有線]─ Type 2BP EVK (QN9090 + SR150 UWB)

                                    ↕ UWB 6.5GHz (Ch5/9)

[ ドラゴンボール (タグ) × 7 個 ]
  Type 2DK EVK (QN9090 + SR040 UWB)
    + 樹脂筐体 (3D プリント、内側に光ファイバー散らし)
    + 単 4 電池 × 2
```

ESP32-P4 と Type 2BP は **物理 UART** で直接配線する。WiFi / BLE は技適まわりの判断から使わない。

## 工程と現状

| Phase | 内容 | 状態 |
|---|---|---|
| 0 | 部品入手、SDK 入手、開発環境構築 | ✅ |
| 1 | ESP32-P4 上で LCD + Bandai UI が動く (ダミーデータ) | ✅ |
| 2a | NXP UWBIOT SDK の MCUXpresso ヘッドレスビルド検証 | ✅ |
| 2b | QN9090 ファーム改造で UWB ranging 結果を ASCII で吐かせる | ✅ |
| 2c | 改造ファームを焼いて、UART 3Mbps で距離 + 方位が流れることを実機確認 | ✅ |
| 2d | ESP32-P4 ↔ Type 2BP の物理 UART 配線 + LVGL に実データ反映 | 進行中 |
| 3 | ドラゴンボール側 (Type 2DK) のタグ化 ファーム + 筐体 | これから |
| 4 | 音声 / 効果音 / BGM | これから |
| 5 | 全体筐体 CAD + 組立 | これから |

開発開始は 2026-04-29、応募締切は 2026-06-22。**今のところスケジュールに 1 週間以上の余裕**がある。

## なぜここに書くか

この作品は趣味として作るが、過程で得た技術知見 (UWB / NXP UWBIOT SDK / ESP-IDF / LVGL / 組込ハード設計 / 技適) は **同じことをやろうとする人**にも役に立つはず。なので進行中の発見を分割して記事にしていく。

最初に切り出すのは以下:

1. [dk6prog で QN9090 を USB ISP だけで焼く](#) ← SWD ハード無しでもファーム書ける話
2. [MCUXpresso headless build でファームを 10 秒で回す](#) ← IDE を立ち上げずにビルド
3. [UWB ranging が動かない原因は UCI 世代差だった](#) ← 異種 UWB チップを組ませる時のハマりどころ
4. [ESP32-P4 × LVGL で Bandai ドラゴンレーダー UI を作る](#) ← 玩具っぽい温かみある UI を LVGL で
5. [技適未確認ボードをコンテストで使うなら](#) ← 国内出展のための設計判断

本作品の進捗は完成までこのブログで時系列に記録する。完成しなかったらそれもまた記録として残す。

## 期待値の調整

「ドラゴンレーダーが動く」とは何か、最初に明確にしておく:

- ✅ 5 cm 程度の距離精度で**近くにあるボールの距離**が分かる
- ✅ AoA で**ボールの方向 (左右)** が分かる (前後判定は補助的)
- ✅ 7 個まで同時表示できる (round-robin で測距)
- ❌ 壁を貫通する透視能力は無い (UWB は壁 2 枚以上で減衰する)
- ❌ 「ピッピッ」音は出るが、原作のサーチ音とは違う (著作権)

**現代の物理法則の上で実装可能な範囲で最大限フィクションに近づける**、それが本作品の制約。

完成記事 (動作デモ動画 + 全工程まとめ) は 6/22 直前に公開予定。それまでは過程の知見を順次共有する。

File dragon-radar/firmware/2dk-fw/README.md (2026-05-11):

# 2DK QN9090 カスタムファームウェア (Path C)

タグ側 (2DK EVK) の QN9090 で動かす Responder 専用 FW。電源 ON で待機し、2BP からの TWR 要求に自動応答する。

## 必要な前提

- 2BP と同じ (NXP UWBIOT SDK / Murata パッチ / MCUXpresso / MCU-Link Pro / ARM GCC)
- ただし SR040 用の demo_ranging_responder サンプルをベースにする
- Murata 出荷時 FW は Initiator 固定なので、**この Responder FW は必須**

## ビルド手順 (Phase 3 で確定)

```bash
cd firmware/2bp-config/sdk/UWBIOT_SR150_*_SEGGER/uwbiot-top
cd boards/Host/Rhodes4
make demo_ranging_responder TARGET=QN9090 SR040=1
```

## 設定項目

各 2DK ごとに**異なる UWB MAC アドレス**を設定する (ranging session で識別するため):

```c
// config.h
#define UWB_DEVICE_MAC      0xABCD0001  // 個体毎に変える: 0001, 0002, 0003 ...
#define RANGING_TIMEOUT_MS  100         // controller からの poll 待機 timeout
#define LOW_POWER_MODE      1           // CR2032 駆動なので消費電流抑制
```

## ファイル配置 (Phase 3 で実装予定)

```
2dk-fw/
├── README.md       (このファイル)
├── src/
│   ├── main.c
│   ├── responder.c/h    # SR040 を Responder として常駐
│   └── config.h         # UWB MAC、低電力設定
└── prj/                 # MCUXpresso プロジェクト
```

## 個体管理

7 個の 2DK タグに以下の情報を物理的にラベリングしておく:

| タグ ID | UWB MAC | ドラゴンボール色 | シリアル番号 (基板) |
|---|---|---|---|
| 1 | 0xABCD0001 | 赤 | (Phase 3 で記入) |
| 2 | 0xABCD0002 | 橙 | |
| 3 | 0xABCD0003 | 黄 | (9月用追加分) |
| 4 | 0xABCD0004 | 緑 | |
| 5 | 0xABCD0005 | 水色 | |
| 6 | 0xABCD0006 | 青 | |
| 7 | 0xABCD0007 | 紫 | |

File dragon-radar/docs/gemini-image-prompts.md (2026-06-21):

# Gemini 画像生成 指示書 ─ ドラゴンレーダー 提出用ビジュアル

実機写真2枚をGemini（Nano Banana / Gemini 画像編集）に添付し、下のプロンプトをコピペして提出用画像を作る。

## 素材（添付する実写）
- **A: ドラゴンボール（一星球）** … オレンジ半透明レジン球、中央に赤い5芒星（1つ星）、表面に小さな排液穴。`IMG_1586.jpg`
- **B: レーダー本体** … 白い円形3Dプリント筐体＋丸い緑のレーダー画面（グリッド／スイープ扇／中央のピンク三角＝自機／**黄色い光点＝検出したボール**）。`IMG_1587.jpg`

## 大前提（重要・全プロンプト共通）
- **実物の形・色・質感・画面表示は変えない**（コンテスト応募なので“盛り”は背景/光/構図まで。デバイスや球の見た目・レーダー画面のグリッドや光点を捏造しない）。
- 出力は **16:9・880×495px以上**（ProtoPediaのメイン/構成図推奨サイズ）。1枚目がメイン画像。
- 余計な文字・ロゴは入れない。

---

## ① メインビジュアル（A+B 合成・最重要）
```
添付2枚を1枚に合成してください。
・1枚目(A)=オレンジ半透明の樹脂製“ドラゴンボール”（中央に赤い1つ星）。
・2枚目(B)=丸い緑のレーダー画面を持つ白い円形デバイス。
両方を、暗くクリーンな背景（黒〜濃紺のグラデーション、ソフトな反射のある滑らかな台）に置いたプロダクト写真風に合成。
構図: レーダー(B)を左手前、ドラゴンボール(A)を右奥にやや小さく配置。
演出: レーダー画面の“黄色い光点”からドラゴンボールへ向かう、淡い光のライン／グローを描き「電波で探知している」様子を表現。
維持すべき点: デバイスと球の形・色・質感、レーダー画面の緑のグリッド・中央の三角・黄色い光点は元写真のまま、くっきり鮮明に。
ライティング: シネマティックで上質。被写界深度で背景を軽くボカす。
出力: 16:9・高解像度。
```

## ② ドラゴンボール単体（クリーン）
```
添付のオレンジ色樹脂ドラゴンボール（赤い1つ星）の写真を、
背景を暗い無地（黒〜濃グレー、下にソフトな鏡面反射）に置き換えてください。
半透明レジンが内側から淡く発光するような“ガラス玉”の質感を強調し、赤い星は鮮やかに。
球の形・色・彫り込みの星・表面の質感は元のまま維持。捏造しない。
プロダクト写真風、被写界深度あり、16:9・高解像度。
```

## ③ レーダー本体単体（画面を主役に）
```
添付の白い円形レーダーデバイスの写真から、ごちゃついた背景（3Dプリンタ・ケーブル・机）を消し、
暗い無地のスタジオ背景に置き換えてください。
丸い緑のレーダー画面（グリッド／スイープ扇／中央のピンク三角／黄色い光点）は元のまま、明るくくっきりと。
白い筐体のマットな質感、上部の丸いボタンも維持。
卓上に置いた、または手に持つプロダクト写真風。16:9・高解像度。捏造しない。
```

## ④ システム構成図のベース（任意）
```
クリーンでモダンなテック系の構成図を作ってください（フラットデザイン、白背景）。
要素: 「ドラゴンボール(UWBタグ)」→(UWB測距/AoA)→「レーダー本体(UWB 2BP)」→(UART)→「ESP32-P4 + 丸型LCD」、
さらに「BNO086 IMU(方位)」と「ボタン(レンジ切替)」がESP32-P4に接続。
矢印とアイコンで信号の流れを示す。文字は日本語。16:9。
```
> ※構成図は写真合成より、図として別途作る方が正確。テキスト版の図が要れば私が出します。

---

## 使い方メモ
1. Gemini に **該当する実写を添付** → 対応プロンプトを貼る。
2. 出てきた画像を確認し「背景もっと暗く」「光点を強調」等で微調整。
3. ProtoPedia：①をメイン(1枚目)、②③を続けて、構成図を4〜5枚目に。
4. 仕上がりが**実機と乖離しすぎたら採用しない**（応募の信頼性優先）。

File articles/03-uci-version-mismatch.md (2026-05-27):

# UWB ranging が動かない真犯人は「UCI 世代差」だった話

## 要約

異なる NXP UWB チップ (SR150 / SR040) を載せた 2 つの評価ボードを ranging させようとしたら、

- 両者の `RANGE_DATA_NTF` (測距結果通知) に乗っている **session ID が違って見える**
- 一方は `0x00000001`、もう一方は `0x11223344`

「session ID が違うから pair しないんだ」と最初は誤診したが、SDK のソースを当たると **両方ともデフォルトで `0x11223344` を設定している**ことが判明。

実際に違うのは UCI (UWB Command Interface) のプロトコル世代で、UCI v1.x は `Session ID` を payload にそのまま乗せるが、UCI v2.0 以降は `Session Handle` というラッパに置き換わる。**通知フィールドが見た目同じバイト位置でも、解釈が違うので一致しない**。

両方を **UCI v1.31 世代の SDK に揃えた瞬間に ranging が成立**した。誤診から本質に辿り着くまでの記録。

## 環境

- Initiator: NXP SR150 ベースの評価ボード (Murata Type 2BP EVK Rev 4.1)
- Responder: NXP SR040 ベースの評価ボード (Murata Type 2DK EVK)
- 両者にメーカープリビルド済の standalone ranging デモを焼いて、UART 経由で生の UCI トレースを観察

## 最初の観測

電源を入れて並べると、2 つの EVK はとりあえずお互いの存在は認識する (TX/RX が走る) のだが、**ranging が完了しない**。Murata 提供の Python テストスクリプトも distance を 1 度も print しないまま終わる。

両方の UART を `cat /dev/ttyUSB*` で生キャプチャして UCI フレームを抜き出すと、

- 2BP (SR150 / 新しい SDK) 側: NTF 内の session 識別フィールドが `01 00 00 00` (リトルエンディアン解釈で `0x00000001`)
- 2DK (SR040 / 古い SDK) 側: 同じ位置が `44 33 22 11` (リトルエンディアン解釈で `0x11223344`)

ぱっと見「2 つの session ID が違う、だから ranging が成立しない」と読みたくなる。これが間違いだった。

## SDK のソースを当たる

それぞれの SDK のサンプルコードを `grep -nrR SESSION_ID` する。

```
demos/SR1XX/demo_ranging_controller/demo_ranging_controller.c:
  #define RANGING_APP_SESSION_ID 0x11223344

demos/SR040/demo_tracker_sr040/app_Ranging_Cfg.h:
  #define RANGING_APP_SESSION_ID 0x11223344
```

両方とも **`0x11223344` を設定している**。つまりアプリケーション層で投げているセッション ID は一致しているはず。

ということは、UART で見ている「session 識別フィールド」がそもそも別物を指している可能性が高い。

## UCI 仕様書を読み直す

NXP の SR150 UCI Specification を当たると、v1.x と v2.0 で `RANGE_DATA_NTF` の最初の数バイトの定義が変わっている:

| バイト位置 | UCI v1.x | UCI v2.0 |
|---|---|---|
| 0-3 | Sequence Number | Sequence Number |
| 4-7 | **Session ID** (アプリが設定した 32-bit 値そのまま) | **Session Handle** (UCI スタックが割り当てた識別子) |
| 8-11 | Rcr Block Index | Rcr Block Index |
| ... | ... | ... |

v2.0 で導入された **Session Handle** は SDK 内部で `SessionInit` 時に動的に発行される (例: `0x00000001` から順に割り当てる) 識別子で、アプリが設定した Session ID とは別物。アプリ層 API では Session ID を渡すが、UCI バイナリ層では Handle に置き換わる。

つまり、

- SR150 + 新しい SDK: UCI v2.0 → NTF の 4-7 バイト目には **Session Handle (`0x00000001`)** が乗る
- SR040 + 古い SDK: UCI v1.x → NTF の 4-7 バイト目には **Session ID (`0x11223344`)** がそのまま乗る

両者は同じバイト位置に別の意味の値を入れていて、当然 ranging session の照合に失敗する。**「session ID が違う」のではなく「session 識別の規約が違う」が本質**だった。

## 揃え方

選択肢は 2 つ:

1. SR040 側の SDK を v2.0 世代に上げる
2. SR150 側の SDK を v1.x 世代に下げる

SR040 はメーカー (Murata) が校正済の standalone バイナリを v1.x 世代でしか出してくれていなかったので、現実解は (2)。**SR150 側を NXP UWBIOT SDK v04.04.03 (UCI v1.31) の bare バイナリに差し替え**、両者の UCI 世代を v1.31 に統一した。

結果: 焼き直して電源入れた瞬間、UART に `TWR[0].distance : 26` のような distance 値が湯水のように流れ始めた。20 秒で 200+ サンプル、distance は両端で平均 0.5cm 以内に一致 (DS-TWR が正しく完走している証拠)。

## 教訓

- **「session ID が違う」のように『見える』状態を素直に取らない**。NTF のバイト位置と UCI 仕様書の世代を必ず照合する
- **異種チップを組ませる時は UCI 仕様の世代揃えが必須**。SR150 と SR040 は同じ NXP 製でも世代が異なる SDK で出てくる
- **デバッグの第 1 歩は SDK ソースの grep**。「定数として何を設定しているか」を直接確認すれば、UART で観測した値との差分が見える

UCI が業界標準 (FiRa Consortium 仕様) になりつつあるとはいえ、世代差を吸収するレイヤはまだ薄い。**UWB を触る時は両端の SDK バージョンを意識して揃えること**が、ranging を素直に動かす近道。

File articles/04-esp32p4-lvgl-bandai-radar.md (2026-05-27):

# ESP32-P4 × LVGL で「バンダイ ドラゴンレーダー」風 UI を本気で再現する

## 要約

ESP32-P4 + 800×800 円形 LCD (Waveshare 3.4C / IPS) という贅沢なハードで、**1980 年代バンダイから出ていた玩具版「ドラゴンレーダー」の画面表示**を再現してみた記録。

ポイントは 4 つ:

1. **色** ── 緑 CRT 背景 + 太い黒グリッド + ゴールド数字 + コーラル三角ポインタ
2. **三角ポインタ** ── 「現在地」を表す塗り潰し三角を LVGL の `lv_obj` 矩形スタックで描く (LVGL 9 にはネイティブの三角プリミティブが無いため)
3. **スイープ** ── 円弧 30 度幅の `lv_arc` を回し続ける
4. **光点 (ドラゴンボール)** ── 距離→対数スケール、AoA 方位→極座標変換で配置

LVGL は工業 HMI に最適化されていて「アニメ・玩具風の温かみある画面」を作るのが意外と難しい。本記事はその難易度をどう越えたかの記録。

## ハードと前提

- **MCU**: ESP32-P4 (RISC-V dual-core 400MHz、PSRAM 32MB)
- **LCD**: 800×800 round IPS (Waveshare 3.4C)
- **フレームワーク**: ESP-IDF v5.5.4、LVGL 9.5.0、esp_lvgl_adapter 経由
- **描画モード**: triple partial buffer + tear-avoid

LCD は MIPI-DSI で繋がっていて、フレームバッファは PSRAM に乗る。Waveshare BSP (`waveshare/esp32_p4_wifi6_touch_lcd_xc`) を managed component で取り込めば LVGL までの配線は数行で済む。

## カラーパレット

玩具版の写真を観察してパレットを取った:

```c
// theme.h
#define DR_COLOR_BG       lv_color_hex(0x2A9040)  // 緑 CRT
#define DR_COLOR_GRID     lv_color_hex(0x001008)  // ほぼ黒
#define DR_COLOR_SWEEP    lv_color_hex(0xA0FFB0)  // スイープのトレイル
#define DR_COLOR_TEXT     lv_color_hex(0xFFD700)  // ゴールド (数字 / ラベル)
#define DR_COLOR_DOT      lv_color_hex(0xFFC800)  // ドラゴンボール (オレンジゴールド)
#define DR_COLOR_POINTER  lv_color_hex(0xFF6E50)  // コーラル (中央三角)
```

ポイントは **背景の緑をくすませる** こと。サチった #00FF00 を使うと「LED マトリクス」っぽくなり玩具感が消える。 #2A9040 くらいの**やや暗くて青みのある緑**が CRT 蛍光体っぽくて良い。

## グリッド

LVGL の標準では「画面全体に等間隔の格子線」を引くプリミティブは無いので `lv_line_create` を縦横ループで配置する。

```c
#define GRID_STEP 50
for (int x = GRID_STEP; x < DR_SCREEN_SIZE; x += GRID_STEP) {
    static lv_point_precise_t pts[20][2];
    int i = x / GRID_STEP - 1;
    pts[i][0].x = x; pts[i][0].y = 0;
    pts[i][1].x = x; pts[i][1].y = DR_SCREEN_SIZE;
    lv_obj_t *line = lv_line_create(parent);
    lv_line_set_points(line, pts[i], 2);
    lv_obj_set_style_line_color(line, DR_COLOR_GRID, 0);
    lv_obj_set_style_line_width(line, 2, 0);
    lv_obj_set_style_line_opa(line, LV_OPA_80, 0);
}
```

`lv_point_precise_t` は **static** にしないと描画タイミングでスタック上のメモリが消えて画面に変な線が現れる。LVGL のプリミティブはポインタを保持するだけで、内部コピーしないことが多いので注意。

## 三角ポインタ ── 一番苦戦したパーツ

LVGL 9 に **塗り潰し三角プリミティブは無い**。`lv_canvas` で自前描画してもいいが、800×800 のフルキャンバスを PSRAM に保持するのは重い。

そこで採用したのが **水平スキャンラインで矩形を積む方式**:

```c
#define PT_SIZE 16     // 三角の半幅
#define PT_STEP 2      // スキャンラインの厚さ
const int y_top    = DR_CENTER - PT_SIZE;
const int y_bottom = DR_CENTER + PT_SIZE / 2;
const int height   = y_bottom - y_top;

for (int y = y_top; y <= y_bottom; y += PT_STEP) {
    int dy = y - y_top;
    int half_w = (dy * PT_SIZE) / height;
    if (half_w < 1) half_w = 1;

    lv_obj_t *seg = lv_obj_create(parent);
    lv_obj_remove_style_all(seg);
    lv_obj_set_size(seg, half_w * 2, PT_STEP);
    lv_obj_set_pos(seg, DR_CENTER - half_w, y);
    lv_obj_set_style_bg_color(seg, DR_COLOR_POINTER, 0);
    lv_obj_set_style_bg_opa(seg, LV_OPA_COVER, 0);
}
```

頂点が上、底辺が下の塗り潰し三角を、PT_STEP=2 ピクセル幅の矩形を ~12 個積んで再現する。**メモリは矩形 12 個分しか食わない** (内部的に lv_obj は数百バイト)。LVGL の合成エンジンが矩形描画はべらぼうに速いので描画コストもタダ同然。

回転させたい場合は `lv_obj_set_style_transform_angle` でグループ全体を回せばよい。三角ポインタを「機体の向きに合わせて回転」させる用途にも使える。

## スイープアーク

円弧を回すのは LVGL のお家芸:

```c
lv_obj_t *arc = lv_arc_create(parent);
lv_obj_set_size(arc, DR_RADAR_RING_R2 * 2, DR_RADAR_RING_R2 * 2);
lv_obj_align(arc, LV_ALIGN_CENTER, 0, 0);
lv_arc_set_bg_angles(arc, 0, 360);
lv_arc_set_rotation(arc, 270);
lv_arc_set_angles(arc, 0, 30);  // 30 度幅
lv_obj_set_style_arc_color(arc, DR_COLOR_SWEEP, LV_PART_INDICATOR);
lv_obj_set_style_arc_width(arc, DR_RADAR_RING_R2, LV_PART_INDICATOR);
lv_obj_set_style_arc_opa(arc, LV_OPA_30, LV_PART_INDICATOR);

lv_anim_t a;
lv_anim_init(&a);
lv_anim_set_var(&a, arc);
lv_anim_set_exec_cb(&a, (lv_anim_exec_xcb_t)lv_arc_set_rotation);
lv_anim_set_values(&a, 270, 270 + 360);
lv_anim_set_duration(&a, 1500);
lv_anim_set_repeat_count(&a, LV_ANIM_REPEAT_INFINITE);
lv_anim_start(&a);
```

`arc_width = R2` (リング全径) にして、塗り部分の不透明度を 30% に落とすと「スポットライトが回転する」風になる。トレイル感を出したいなら 2 本目のアークを反対側に置いて opa=10% にする手もある。

## 光点 (ドラゴンボール) 配置

UWB ranging から流れてくる `distance_mm` と `azimuth_deg` を画面座標に変換する:

```c
static int32_t distance_to_radius_px(uint16_t distance_mm) {
    if (distance_mm == 0) return 0;
    if (distance_mm >= DR_RANGE_MAX_MM) return DR_RADAR_RING_R2;
    float ratio = logf(1.0f + (float)distance_mm / 1000.0f)
                / logf(1.0f + (float)DR_RANGE_MAX_MM / 1000.0f);
    return (int32_t)(DR_RADAR_RING_R2 * ratio);
}

static void polar_to_cartesian(uint16_t distance_mm, int16_t azimuth_deg,
                               int32_t *x, int32_t *y) {
    int32_t r = distance_to_radius_px(distance_mm);
    float az_rad = azimuth_deg * M_PI / 180.0f;
    *x = DR_CENTER + (int32_t)(r * sinf(az_rad));
    *y = DR_CENTER - (int32_t)(r * cosf(az_rad));
}
```

距離 → 半径は **対数スケール**にする。線形だと「近い時は中心にくっつく、遠い時はリングの端に張り付く」となるが、人間の空間感覚に合うのは対数。1m での解像度を大きく取り、10m の精度を犠牲にする。

光点本体は丸オブジェクトに **シャドウで発光感**を出す:

```c
lv_obj_t *dot = lv_obj_create(parent);
lv_obj_set_size(dot, 30, 30);
lv_obj_set_style_radius(dot, LV_RADIUS_CIRCLE, 0);
lv_obj_set_style_bg_color(dot, DR_COLOR_DOT, 0);
lv_obj_set_style_shadow_color(dot, DR_COLOR_DOT, 0);
lv_obj_set_style_shadow_width(dot, 28, 0);
lv_obj_set_style_shadow_opa(dot, LV_OPA_70, 0);
```

`shadow_width = 28` (本体径とほぼ同じ) で**等方ハロー**ができ、ドラゴンボールの「内側から光ってる」雰囲気が出る。

## ハマりどころメモ

| 症状 | 原因 / 対処 |
|---|---|
| 起動時にリンカが `--enable-non-contiguous-regions discards section ... 21KB` | ESP32-P4 v1.x シリコンで `CONFIG_SPIRAM_XIP_FROM_PSRAM` 有効だと IRAM 溢れ → 無効化 |
| LCD が真っ黒 | `CONFIG_LV_USE_PERF_MONITOR=n`、`COMPILER_OPTIMIZATION_SIZE=y`、L2 cache 128KB に落とす |
| 描画がカクつく | `LV_COLOR_DEPTH=16`、frame buffer を PSRAM に置く、`triple_partial` モード |
| 緑がサチった LED 色になる | パレットを `#2A9040` 系のくすんだ緑に。`#00FF00` は使わない |

## 動かしてみた

LCD のフォトを撮って横で玩具のドラゴンレーダーと比較した時、**「電池入れて 30 年経った玩具」っぽい質感**が出てしまった (緑が少しくすんでいる + 黒グリッドが太い + フォントがゴールド) ── 結果としてその"古色感"が逆に良かった。

LVGL は HMI 用ライブラリだけど、**プリミティブを工夫すれば「玩具・アニメ的な温かみのある UI」も十分作れる**。三角プリミティブが無いから諦める前に、矩形スタックで作れないか考えてみる価値はある。

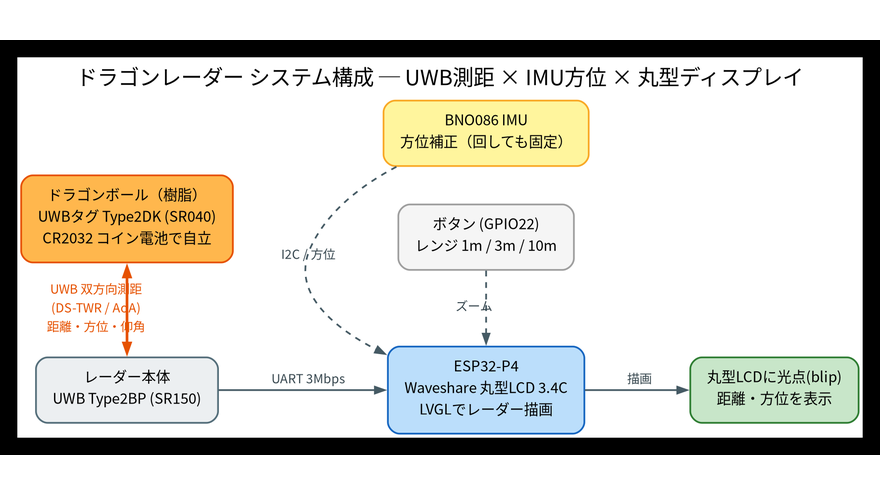
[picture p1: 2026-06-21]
dragon-radar/docs/system-diagram.png

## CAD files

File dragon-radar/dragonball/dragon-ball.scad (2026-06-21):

// ============================================================================
//  Dragon Ball — UWBタグ球体ケース (parametric)
//  本番: AnyCubic Photon M3 (レジン/MSLA, RESIONE かえんオレンジ水洗い)
//  プロト: Bambu A1 (FDM) でも可。星は印刷後に赤を差し塗り。
//  2半球分割: レジンはスライサが向き/サポートを付与。FDMは切断面下+ドーム頂部に軽サポート。
// ============================================================================
$fn = 160;

// ---- 主要パラメータ ----
ball_dia    = 70;    // 外径 [mm] (原作 ~75)
wall        = 2.2;   // 殻厚 (レジンは脆いので2mm以上)
star_count  = 1;     // 星の数 1..7 (DigiKey Make ONE Challenge → 一星球=1)
star_d      = 12;    // 星の外径(表面) [mm] (単独星なので大きめで映えさせる)
star_depth  = 1.0;   // 彫り込み深さ [mm]
star_spread = 9;     // 星クラスタの広がり(中心オフセット係数)
lip_h       = 4;     // 接合リップの差し込み高さ
lip_t       = 1.4;   // リップ肉厚
lip_gap     = 0.20;  // リップ嵌合クリア(片側)。レジンはタイトめ
part        = "both";// top / bottom / both / assembly / clip / bottom_print / top_print

// 排液/吸盤対策の穴 (ヘッドレス平置き印刷用。最終ボールは false のまま)
drain_holes      = false;
drain_hole_d     = 3.5;  // 排液穴径
drain_hole_n     = 4;    // 穴数
drain_apex_angle = 45;   // ドーム頂点からの角度(度)。星を避ける

R  = ball_dia/2;
Ri = R - wall;       // 内半径(空洞)

// ---- 5芒星 2D ----
module star2d(d) {
    ro = d/2; ri = d/2*0.40;
    polygon([ for (i=[0:9]) let(a=90 + i*36, r=(i%2==0 ? ro : ri)) [r*cos(a), r*sin(a)] ]);
}

// ---- 星の配置 (局所x,y, -1..1) N=1..7 サイコロ風=ドラゴンボール風 ----
function layout(n) =
    n<=1 ? [[0,0]] :
    n==2 ? [[-0.6,0],[0.6,0]] :
    n==3 ? [[0,0.7],[-0.6,-0.45],[0.6,-0.45]] :
    n==4 ? [[-0.6,0.6],[0.6,0.6],[-0.6,-0.6],[0.6,-0.6]] :
    n==5 ? [[-0.7,0.7],[0.7,0.7],[0,0],[-0.7,-0.7],[0.7,-0.7]] :
    n==6 ? [[-0.7,0.7],[0.7,0.7],[-0.7,0],[0.7,0],[-0.7,-0.7],[0.7,-0.7]] :
           [[-0.7,0.7],[0.7,0.7],[-0.7,0],[0.7,0],[-0.7,-0.7],[0.7,-0.7],[0,0]];

// ---- 星を上極(+Z)に彫る cutter ----
module star_debosses() {
    for (p = layout(star_count)) {
        x = p[0]*star_spread; y = p[1]*star_spread;
        zs = sqrt(max(R*R - x*x - y*y, 1));   // その(x,y)の球面z
        translate([x, y, zs - star_depth])
            linear_extrude(star_depth + 2) star2d(star_d);
    }
}

// ---- 中空球殻 + 星彫り ----
module shell() {
    difference() {
        sphere(R);
        sphere(Ri);
        star_debosses();
    }
}

// ---- 接合リップ (上半球に付け、下半球の空洞に差し込む) ----
//   connector(z>=0, 外径Ri=殻内壁とオーバーラップ) + insert(z<0, 外径Ri-gap=差込部)
module join_lip() {
    difference() {
        union() {
            cylinder(h = wall*2, r = Ri);                 // connector: 殻と一体化
            translate([0,0,-lip_h]) cylinder(h = lip_h, r = Ri - lip_gap); // insert
        }
        translate([0,0,-lip_h-0.1])
            cylinder(h = lip_h + wall*2 + 0.2, r = Ri - lip_gap - lip_t);  // 中空
    }
}

// 排液穴 (pole: +1=上半球頂点+Z / -1=下半球頂点-Z)。ドーム頂点から drain_apex_angle で穿孔
module drain_cuts(pole) {
    for (i = [0:drain_hole_n-1])
        rotate([0, 0, i*360/drain_hole_n + 45])
            rotate([0, pole > 0 ? drain_apex_angle : 180 - drain_apex_angle, 0])
                translate([0, 0, R])
                    cylinder(h = wall + 6, d = drain_hole_d, center = true);
}
module half_top() {   // 星のある側
    difference() {
        union() {
            intersection() { shell(); translate([0,0,-0.001]) cylinder(h=R+1, r=R+1); }
            join_lip();
        }
        if (drain_holes) drain_cuts(1);
    }
}
module half_bottom() {
    difference() {
        intersection() { shell(); translate([0,0,-R-1]) cylinder(h=R+1, r=R+1); }
        if (drain_holes) drain_cuts(-1);
    }
}

// ---- 出力 ----
if (part == "assembly") {
    half_bottom();
    color("orange", 0.55) half_top();
} else if (part == "top") {
    half_top();
} else if (part == "bottom") {
    half_bottom();
} else if (part == "bottom_print") {   // 平置き向き(切断面を下=ベッド、ドーム上)
    rotate([180,0,0]) half_bottom();
} else if (part == "top_print") {      // 上半球は自然向きで切断面が下
    half_top();
} else if (part == "clip") {        // 断面確認
    intersection() {
        union() { half_bottom(); half_top(); }
        translate([-200,0,-200]) cube([400,200,400]);
    }
} else {                            // both: 並べて表示
    translate([-R-4, 0, R]) rotate([180,0,0]) half_top();  // 切断面を下に
    translate([ R+4, 0, R])                    half_bottom();
}

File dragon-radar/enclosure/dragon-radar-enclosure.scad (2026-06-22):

// =============================================================================
//  Dragon Radar UWB — Enclosure (筐体) v0.2
//  DigiKey Make ONE Challenge 2026
//
//  ターゲット: Waveshare ESP32-P4-WIFI6-Touch-LCD-3.4C (丸型一体モジュール)
//  印刷: FDM / PLA / ベッド ~220mm (ø一体造形)
//
//  v0.2 変更点:
//    - ベゼル⇔本体: 環状スナップフィット (連続ビード+溝)。前面ネジ無し。
//    - 本体上端を段付き「トング」化し、スカートを被せて外周 ø121 を面一に。
//    - バックカバー: M3 セルフタップ 4本留め (後方空洞のボスに固定)。
//    - v0.1 の嵌合バグ修正 (スカートと壁の干渉 / ガラス前面の押さえ面欠落)。
//
//  座標系:
//    +Z = 画面側 (ユーザーに向く向き)。Z=0 は前面ガラス表面。
//    モジュール本体は -Z 方向へ伸びる。 +Y = 筐体「上」(ボタン側)。
//
//  ⚠ 寸法の出典: README.md 参照。[MEASURE] 印は現物到着後に実測確定する仮値。
// =============================================================================

// ---- レンダリング対象 -------------------------------------------------------
//  assembly / bezel / body / back / board
part = "assembly";
clip = false;              // true: Y>=0 半割り断面表示 (嵌合確認用、非出力)

$fn = 120;                 // 最終出力前は 180+ 推奨

// ====================== ボード (3.4C) 実寸 ===================================
board_glass_dia   = 115.0; // ガラス/前面外形 [確定]
board_active_dia  = 87.6;  // 有効表示エリア径 [確定]
board_glass_th    = 6.0;   // 前面ガラス厚 [確定]
board_stack_th    = 14.0;  // モジュール総厚 [実測 2026-05-31]
// 背面キャリア基板 (四角) [実測 2026-05-31: 65×86]
carrier_x         = 86.0;  // 長辺
carrier_y         = 65.0;  // 短辺
carrier_angle     = 180;   // 取付向き: USB-C(上辺)を筐体底(270°)へ→ USB-A右0/microSD左180
carrier_th        = board_stack_th - board_glass_th; // ガラス背面〜最深部 ≈8

// マウント穴 (四隅ではない) [MEASURE]
//   キャリア中心を原点、長辺=X として [x,y] で実測位置を列挙する。
//   実測 2026-05-31 (すべて外形込み→穴芯はスタンドオフ径ぶん内側): 上下非対称な台形。
//   列間X=83.6 / 左列Y間隔32(上端→上ネジ8.6) / 右列Y間隔39(上端→上ネジ8.3)。
//   中心原点・上端+32.5。左上=32.5-8.6=23.9, 右上=32.5-8.3=24.2。
mount_holes       = [[-41.8, 23.9],[-41.8, -8.1],   // 左列: Y間隔32
                     [ 41.8, 24.2],[ 41.8,-14.8]];  // 右列: Y間隔39
mount_hole_dia    = 2.5;

back_clear        = 8.0;   // PCB 背面〜バックカバー内面の隙間 [MEASURE]

// ====================== 筐体基本パラメータ ===================================
//  素材: Bambu A1 / PLA Matte (FDM)。2026-06-14 実機クーポンで検証:
//   薄壁(wall3.2)スナップは爪が薄く(~1.2mm)ビードも浅く保持せず→壁厚化で爪剛性+噛み深さUP
//   ボタン穴12.3=ぴったり / 嵌合は厚壁版(下記)でカチッと保持を確認
wall              = 4.4;   // 側壁厚 (トング壁2.2/爪剛性確保。薄壁だとスナップが保持しない)
side_clear        = 0.6;   // モジュール外周と内壁のクリアランス(片側)
bezel_overlap     = 2.0;   // ベゼルがガラス前面を抑える掛かり代(径方向)
bezel_face_th     = 2.5;   // 前面ベゼル板厚
back_th           = 2.4;   // バックカバー板厚

// 派生
inner_dia  = board_glass_dia + 2*side_clear;     // 内壁径 ≈116.2
outer_dia  = inner_dia + 2*wall;                 // 外径 ≈125.0 (wall=4.4, スナップ強化で増)
window_dia = board_active_dia + 2*bezel_overlap; // 窓径 ≈91.6
R_out      = outer_dia/2;
R_in       = inner_dia/2;

// 深さ(Z)
depth_inner = board_stack_th + back_clear;       // 内寸深さ ≈23
outer_depth = bezel_face_th + depth_inner + back_th; // 総厚 ≈27.9 (目標30以内)

// ---- 固定方式: ベゼル環状スナップ ------------------------------------------
skirt_wall  = 2.2;         // ベゼルスカート厚(爪実厚=skirt_wall-fit_gap≈1.9mm。薄いと保持せず)
tongue_h    = 7.0;         // 本体上端トング高さ (スカートが被る)
fit_gap     = 0.30;        // 摺動隙。FDM/PLA実機で確定(2026-06-14)。020/030/040は体感差小=頑丈
R_tongue    = R_out - skirt_wall;        // 本体トング外半径
R_skirt_in  = R_tongue + fit_gap;        // ベゼルスカート内半径
snap_bead   = 1.2;         // ビード/溝量。保持代=snap_bead-fit_gap=0.9(厚壁トングで深く噛む)
snap_h      = 1.6;         // ビード/溝の軸方向高さ
snap_lead   = 1.0;         // リードイン面取り(camを軽く: 0.8→1.0)
snap_z      = -tongue_h + 3.0;           // ビード/溝の中心Z
// ベゼルスカートをスリットで分割しバネ爪化(「バネ」対策)。snap_slots=0 で無効
snap_slots  = 12;          // バネ爪の本数
snap_slot_w = 1.4;         // スリット幅(周方向)
slot_z_top  = -1.5;        // フィンガー根元を残すZ (face側)
slot_z_bot  = -(tongue_h + 1.0); // 下端を確実に切る
snap_groove_h = snap_h + 1.4;    // 溝の軸方向を太く(ビードに遊び=「幅溝を太く」対策)

// ---- バックカバー ネジ (M3 セルフタップ) -----------------------------------
screw_dia    = 3.0;
screw_pilot  = 2.6;        // PLA セルフタップ下穴
screw_head   = 6.0;        // 頭ザグリ径
screw_head_h = 2.6;
boss_dia     = 7.5;
screw_n      = 4;
screw_a0     = 45;
screw_pcd    = inner_dia - boss_dia + 3.0;  // ≈111.7 ボスを壁に食い込ませ一体化 (浮き防止)
// バックの「削り不要化」: 嵌合リップ(solid disk)が本体の受けボス(ø7.5)と半径方向で干渉し、
//   ネジ穴周りを毎回削っていた。リップ側にボス径+余裕の逃げを彫り、貫通にも遊びを持たせる。
back_screw_hole  = screw_dia + 1.6;   // 貫通クリア ≈4.6 (アライメント遊び)
back_screw_cbore = screw_head + 1.0;  // 頭ザグリ ≈7.0
back_boss_clear  = boss_dia + 2.5;    // リップに彫る本体ボス逃げ ≈10.0 (干渉解消=削り不要)

// ---- ピンヘッダ逃がし窓 (バックカバー) -------------------------------------
//  40ピンヘッダ+ジャンパ(IMU/UWB/ボタン)のコネクタが back_clear=8 を超えて突き当たり
//  バックが閉まらない問題 → ヘッダ位置(USB-C側=270°)にプレート+リップ貫通の窓を開ける。
pin_relief       = true;
pin_relief_angle = 270;   // ヘッダ位置: USB-C側(筐体底)。現物で±微調整可
pin_relief_w     = 42;    // 周方向(弦)幅: 40ピンヘッダ+コネクタ長
pin_relief_d     = 17;    // 径方向幅
pin_relief_rc    = 28;    // 窓中心の半径(ヘッダ列の位置)。外へ寄せるなら増やす
pin_relief_ext   = 12;    // 片側(+X/USB-A側「右」)へ追加延長 [mm]。右端X=21+ext=33→右下(315°)ネジ穴の手前まで(ボス逃げ34.5の1.5mm手前)。左端は維持
pin_relief_off   = pin_relief_ext/2;  // 中心シフト(左端維持で右へ伸ばす)。符号を負にすると左へ伸ばす

// ---- ボード固定 (バックカバー→台形マウント穴へ締結) [VERIFY] ----
//   カラーでボード⇔ディスプレイ締結済の上に、バックから4本でサンドイッチを筐体固定。
board_screw_dia    = 2.5;   // M2.5 想定 (現物の穴径で確定)
board_boss_dia     = 7.5;   // 受けボス外径 (頭ザグリ周囲に≥1mm壁を残すため太く)
board_screw_head   = 5.2;   // 頭ザグリ径
board_screw_head_h = 2.4;

// ---- ボタン (MKBKLLJY ø12 メタル momentary + 緑LEDリング, 12V) -------------
//  天面に突出する中空タレットに収める (端子はタレット内、配線のみ内部へ)
//  [VERIFY] 現物 (Phase4-5 で配線済) で寸法確定すること
button_angle     = 90;     // +Y = 天面 (12時方向)
button_z         = -11.0;  // タレット中心Z (本体壁内に収める)
button_dia       = 12.3;   // パネル穴。テスト片で12.3=ぴったり確認(2026-06-03)
// 実測 2026-05-31: 全長24 / 頭(押せる部分)1.7 / 頭先端〜ナット下端6mm
turret_bore      = 16.5;   // タレット内径 (ナット/端子逃げ) [VERIFY: #2 ナット最大径待ち]
turret_wall      = 2.6;    // タレット肉厚
turret_od        = turret_bore + 2*turret_wall; // ≈21.7
turret_protrude  = 14.0;   // 突出長。金属取付部を保持、端子+配線(柔)は内部隙間へ逃がす
turret_cap_th    = 1.8;    // 端面(パネル)厚。ナットねじ代の余裕確保(2.0→1.8) [VERIFY]
turret_clear     = 0.4;    // ベゼル逃げクリアランス
wire_hole_dia    = 5.0;    // 配線通路径

// コネクタ開口の Z (ボタンとは独立)
conn_z           = -(board_glass_th + carrier_th/2); // キャリア深さ中央 ≈-10

// ---- フィンガースカラップ (親指レスト) -------------------------------------
//  薄壁(2.4)+内側モジュールのため深掘り不可 → 局所肉盛りレンズに浅い凹みを彫る。
//  両手持ちの 3/9 時 (0/180°)。空にすれば無効。
scallop_angles   = [30, 150]; // コネクタ(0/180)を避け上側へ。両手親指位置
scallop_z        = -14.5;  // 高さ中央 (ベゼル占有域 z≤-7 より下に収める)
scallop_h        = 11.0;   // 縦長 (Z方向)。top≈-9 でベゼルと非干渉
scallop_padR     = 16.0;   // パッド球半径 (footprint 幅を決める)
scallop_proud    = 3.0;    // 盛り上げ高さ
scallop_cav_r    = 18.0;   // 凹み(縦シリンダ)半径
scallop_depth    = 3.0;    // 凹み深さ (パッド頂点から、floor は元壁面付近で薄肉化させない)

echo(str("outer_dia=", outer_dia, "  outer_depth=", outer_depth, "  window_dia=", window_dia));

// ============================================================================
//  共通ヘルパ: 環状ビード/溝のプロファイル (rotate_extrude)
// ============================================================================
// 内向きビード: 半径 Ri の内面から軸方向に bead だけ突出 (lead 付き台形)
module bead_inward(Ri, bead, h, lead) {
    // 外縁を +0.8 スカート側へ食い込ませ確実に一体化 (面一接触の別ソリッド化を防止)
    rotate_extrude()
        polygon([[Ri+0.8, -h/2-lead], [Ri-bead, -h/2],
                 [Ri-bead, h/2],   [Ri+0.8, h/2+lead]]);
}
// 外向き溝(切削体): 半径 Ro の外面を bead だけ凹ませる矩形リング
module groove_solid(Ro, bead, h) {
    rotate_extrude()
        polygon([[Ro-bead, -h/2], [Ro+1, -h/2],
                 [Ro+1, h/2],     [Ro-bead, h/2]]);
}

// ============================================================================
//  ボード mock (嵌合確認用、非印刷)
// ============================================================================
module board_mock() {
    // 前面: 丸ディスプレイ (ガラス ø115) + 有効表示
    color("DimGray")
        translate([0,0,-board_glass_th]) cylinder(h=board_glass_th, d=board_glass_dia);
    color("Black") translate([0,0,-0.01]) cylinder(h=0.02, d=board_active_dia);
    // 背面: 四角キャリア基板 (65×86)
    color("DarkGreen")
        rotate([0,0,carrier_angle])
            translate([-carrier_x/2, -carrier_y/2, -board_stack_th])
                cube([carrier_x, carrier_y, carrier_th]);
    // マウント穴 (実測リスト)
    color("Gold")
        rotate([0,0,carrier_angle])
            for (h=mount_holes)
                translate([h[0], h[1], -board_stack_th])
                    cylinder(h=carrier_th, d=mount_hole_dia);
}
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

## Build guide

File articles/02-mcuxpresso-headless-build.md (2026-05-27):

# MCUXpresso IDE の headless build で組込ファームを 10 秒で回す

## 要約

NXP が出している MCUXpresso IDE は Eclipse CDT ベースなので、見た目は GUI でも中身は **コマンドラインから単独でビルドを叩ける**。

`mcuxpressoide -application org.eclipse.cdt.managedbuilder.core.headlessbuild` という呪文を覚えてしまえば、IDE を立ち上げる時間も、Eclipse のウィンドウマネージャ周りで詰まる時間もゼロにできて、**1 回 9 秒** でビルドが回るようになる。

「IDE で開いて、メニューから Build をクリックして、終わるのを待って」というループを 10 倍速くしたい人向けの記事。

## なぜ GUI で回すと遅いか

NXP UWBIOT SDK のようなボリュームある SDK を MCUXpresso GUI で開くと、

1. ワークスペースを開くだけで 30 秒以上
2. インデックス再構築で CPU 100% が 2〜3 分
3. Build のたびに「Project Indexer Update」が走り直して数十秒

ソースを 1 行直して焼き直したいだけなのに毎回これに付き合うのは消耗する。

Eclipse CDT は元々 IBM (JDT) から派生した CDT 部分でヘッドレスビルダを持っていて、`-application org.eclipse.cdt.managedbuilder.core.headlessbuild` を渡せば **IDE の UI を起動せずに同じツールチェーンで .project / .cproject をビルドできる**。

## 環境

- Ubuntu 24.04
- MCUXpresso IDE for Linux (`/usr/local/mcuxpressoide-25.6.136/ide/`)
- 内蔵 JRE (OpenJDK 17) と内蔵 arm-none-eabi-gcc を使う

## ヘッドレスビルド呪文

```bash
xvfb-run --auto-servernum --server-args="-screen 0 1024x768x24" \
  /usr/local/mcuxpressoide-25.6.136/ide/mcuxpressoide \
  -nosplash \
  -application org.eclipse.cdt.managedbuilder.core.headlessbuild \
  -data /tmp/mcux-ws \
  -import /path/to/project/MyProject \
  -cleanBuild "MyProject/Debug"
```

各オプションの意味:

| オプション | 意味 |
|---|---|
| `xvfb-run` | Linux サーバや CI で X が無くても Eclipse の GTK 依存を満たす仮想ディスプレイを立てる |
| `-nosplash` | スプラッシュ画面を出さない (ヘッドレスでは不要) |
| `-application <id>` | Eclipse プラットフォームの起動アプリケーションを指定。CDT のヘッドレスビルダはこの ID |
| `-data <dir>` | Eclipse ワークスペース。事前に存在しなくても自動作成される |
| `-import <project>` | `.project` のあるディレクトリ。プロジェクト名はその中身から読み取られる |
| `-cleanBuild "Project/Config"` | クリーンビルドする対象を「プロジェクト名/ビルドコンフィグ名」で指定 |

ポイントは **`Project/Config` がプロジェクト内の `.cproject` に書かれている名前と完全一致しないとダメ** という所。GUI で右クリック → Properties → C/C++ Build → 設定タブのリスト名と一致する。

`.cproject` ファイル内で:

```xml
<configuration name="Debug" ...>
<configuration name="Release" ...>
```

これを grep するのが手っ取り早い。

## 結果

筆者のケース (NXP UWBIOT SDK v04.04.03 + Murata Type 2BP 向け demo_ranging_controller) では:

```
[1/12] Performing build step for 'bootloader'
...
[10/12] Linking CXX executable RhodesV4_SE.axf
Memory region         Used Size  Region Size  %age Used
   PROGRAM_FLASH:      353180 B     629471 B     56.11%
            SRAM:       32576 B        87 KB     36.57%
           SRAM1:         45 KB        64 KB     70.31%
[11/12] Generating binary image
...
Build Finished. 0 errors, 1 warnings. (took 9s.620ms)
```

**9.6 秒**で .axf + .bin まで生成される。GUI で開きっぱなしより速い (差分ビルドなら GUI でも数秒だが、起動時間を含めると勝てない)。

## おまけ: シェル関数化

毎回タイプするのは流石に辛いので zshrc / bashrc に入れておく:

```bash
mcux_build() {
  local proj="$1"
  local cfg="${2:-Debug}"
  xvfb-run --auto-servernum --server-args="-screen 0 1024x768x24" \
    /usr/local/mcuxpressoide-25.6.136/ide/mcuxpressoide \
    -nosplash \
    -application org.eclipse.cdt.managedbuilder.core.headlessbuild \
    -data /tmp/mcux-ws \
    -import "$proj" \
    -cleanBuild "$(basename "$proj")/$cfg"
}

# 使う側
mcux_build /path/to/MyProject Debug
```

これで `mcux_build .` のような短い呼び出しで CI でも開発でも使える。

## ハマりどころメモ

| 症状 | 原因 / 対処 |
|---|---|
| `No projects matched` | `-cleanBuild` の引数が `.cproject` のコンフィグ名と一致してない |
| `DISPLAY 環境変数が設定されてない` | xvfb-run を使う、もしくは X 転送 (`ssh -X`) |
| `Workspace not initialized` | `-data` で指定したパスのパーミッションが書込み不可。`/tmp/` 以下が無難 |
| ビルドが空のサイレント終了 | `-import` のパスが間違っているとログも吐かず終わることがある。絶対パス推奨 |

## 何が良くなったか

- **編集 → ビルド → 焼き** のループが体感 1 桁速くなる
- **CI で組込ファームをビルド** できる。Pull Request ごとにファームのバイナリ差分を取れる
- IDE GUI のメモリ食いが消えるので、開発端末のリソースを LLM チャットや別 IDE に回せる

NXP に限らず Eclipse CDT ベースの組込 IDE (STM32CubeIDE 等) は同じ仕組みで動く。**「IDE を立ち上げてビルドする」習慣をやめると、組込開発の生産性は素直に上がる**。

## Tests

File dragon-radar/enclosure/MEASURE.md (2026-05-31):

# 筐体 実測チェックシート

ボード(ESP32-P4-3.4C)とボタン(MKBKLLJY)の現物を測り、`値` 欄を埋める。
各行の `→ 変数` を [`dragon-radar-enclosure.scad`](dragon-radar-enclosure.scad) に転記すれば確定版になる。

- 工具: ノギス(0.1mm)、分度器 or スマホの角度計、定規。
- 角度の基準: **画面を正面、ボタン(天面)を 12 時=90°** とし、**反時計回り(CCW)に +**。
  USB 側を見て「何時の方向か」を角度に直す (3時=0°, 12時=90°, 9時=180°, 6時=270°)。
- 不明な行は空欄でよい (今の仮値のまま進む)。

---

## 1. ボード外形・厚み (確定値の再確認)

既に確定だが、念のため現物で照合 (違えば上書き)。

| 測る場所 | 仮値 | 実測 | → 変数 |
|---|---|---|---|
| ガラス前面の外径 | ø115.0 | **115.0** ✅ | `board_glass_dia` |
| 有効表示(光る範囲)の径 | ø87.6 | **87.6** ✅ | `board_active_dia` |
| 前面ガラスの厚み | 6.0 | **6.0** ✅ | `board_glass_th` |
| モジュール総厚(ガラス前面〜背面最深部) | 15.0 | **14.0** ⬇ | `board_stack_th` |
| 背面キャリア基板 長辺×短辺 (四角) | — | **86 × 65** ✅ | `carrier_x` / `carrier_y` |
| 背面コネクタ等の最大突出(キャリア背面から) | 8.0 | ______ | `back_clear` |

> 構成判明: **前面=丸ディスプレイ ø115、背面=四角キャリア基板 65×86** (丸の円内に収まる)。
> 丸筐体(ø121)はそのまま有効。

```
   側面(断面)                      前面
  ┌─ガラス厚─┐                    ╭───────────╮
  ▓▓▓▓▓▓▓▓▓▓  ┐                 ╱   ╭─────╮   ╲
  ▓ ガラス  ▓  │総厚            │   │有効 │ ←board_active_dia
  ▓▓▓▓▓▓▓▓▓▓  │stack          │   │表示 │   │
  ░ PCB+部品 ░ │               │   ╰─────╯   │
  ░░░░░░░░░░  ┘                 ╲           ╱
  └back_clear┘(背面突出)          ╰───────────╯
                                  └─board_glass_dia─┘
```

---

## 2. マウントネジ (✅確定: 上下非対称な台形)

カラーでボード⇔ディスプレイ締結済。同じ4穴へバックから締めて筐体固定(二段締め)。

| 項目 | 実測 (外形込み) | → 変数 |
|---|---|---|
| 列間 X | **83.6** → x=±41.8 (端から1.0mm) | `mount_holes` x |
| 左列 Y間隔 / 上端→上ネジ | **32** / **8.6** → y=+23.9, −8.1 | `mount_holes` 左 |
| 右列 Y間隔 / 上端→上ネジ | **39** / **8.3** → y=+24.2, −14.8 | `mount_holes` 右 |
| キャリア向き | USB-C上辺を底へ → **180°** | `carrier_angle` |

> ※すべて「外形込み(スタンドオフ外形)」。穴芯はスタンドオフ径ぶん内側になるので、
> テストプリント時に `mount_holes` / `board_screw_dia` を現物穴芯で微調整する。

```
   キャリア基板を裏から見て (長辺=X=86, 短辺=Y=65)
        +Y(32.5)
   ┌──────────────────┐
   │   ○        ○      │   ○=穴。中心からの x,y を測る
 -X│        ＋中心      │+X   (例: ○が中心右30/上15 → [30,15])
   │       ○           │
   └──────────────────┘
        -Y(-32.5)
   ※基板の長辺(X)が筐体のどの向き(時計)を向くか= carrier_angle
```
> ヒント: 基板の縁から穴芯までの距離を測り、中心(=長辺43.0/短辺32.5)から引いて座標化。

---

## 3. コネクタのリム角度位置 (側壁開口)

各コネクタが**画面を正面に見て何時の方向**にあるかを角度(CCW, 3時=0°)で。
開口寸法 = コネクタの幅×高さ + 抜き差しクリアランス(各+1mm程度)。

| コネクタ | 仮角度 | 実測角度 | 幅(周方向) | 高さ(Z) | → 反映先 |
|---|---|---|---|---|---|
| USB-C (給電/UART) | 250° | ______ | ______ | ______ | `connector_cutout()` 1行目 |
| USB-OTG | 270° | ______ | ______ | ______ | 2行目 |
| microSD | 290° | ______ | ______ | ______ | 3行目 |
| (他に開口が要る物) | — | ______ | ______ | ______ | 追加 |

| その他 | 仮値 | 実測 | → 変数 |
|---|---|---|---|
| コネクタ中心の Z 高さ(ガラス前面=0、背面が −) | −7.5 | ______ | `conn_z` |

```
   側壁を上から見た図 (角度)
            90°
       ┌────●────┐ ←ボタンタレット
   135°│         │45°   ●=各コネクタの中心角を記入
       │  ＋中心  │
   180°│         │0°
       │ ░░░ ░░░ │      ░=コネクタ(底側に集約中)
       └─●─●─●─●─┘
      250 270 290  (現仮値)
            270°
```

---

## 4. ボタン MKBKLLJY (天面タレット) ✅一部確定

ø12 メタル モメンタリ(LED付・配線済)。端子は柔らかいので**金属取付部だけ保持**、
端子+配線は内部の天面隙間へ逃がす設計 → タレットは短くできる。

| 測る項目 | 実測 | → 変数 |
|---|---|---|
| 全長 | **24** | (設計の基準) |
| 頭(押せる部分)の高さ | **1.7** | (頭はタレット外) |
| 頭先端〜ナット下端 | **6** → パネル≤~2 | `turret_cap_th` = **2.0** |
| パネル裏の必要収納 | ~22(柔) → 14で保持+隙間逃がし | `turret_protrude` = **14.0** |
| パネル穴径(バレルØ) | ______ (ふつう ø12) | `button_dia` = 12.3 [VERIFY] |
| 六角ナット最大外径 | ______ | `turret_bore` = 16.5 [VERIFY] |

> 残2つ ([VERIFY]): **バレル径**(ネジ部の太さ=穴径) と **六角ナットの最大外径**。
> 標準ø12なら 12.3/16.5 のままで概ね収まる。テストプリントで現物合わせ。

```
   ボタン側面                タレット(筐体)に収まるイメージ
  ┌──┐ ←頭                 外  ┌────────┐ 内
  │  │                       │ ┌──────┐ │
 ═╪══╪═ ←パネル(厚)→turret_cap_th  ═╪═│ナット │ │
  │  │                       │ │ 端子 │ │→配線穴
  │░░│ ←バレル+ナット         │ └──────┘ │
  │██│ ←端子                  └────────┘
  └┬┬┘                       └全長=turret_protrude目安┘
   配線                       └bore=端子最大径+クリア┘
```

---

## 5. 任意 (フィット感の微調整)

テストプリント or 仮組みで気になれば。

| 項目 | 現値 | 希望 | → 変数 |
|---|---|---|---|
| スナップの渋さ(きつい→+、緩い→−) | gap 0.3 | ______ | `fit_gap` / `snap_bead` |
| 側壁とモジュールの遊び | 0.6 | ______ | `side_clear` |
| スカラップの深さ/高さ | 深3.0 / 高11 | ______ | `scallop_depth` / `scallop_h` |

---

### 記入後の流れ
1. 上の `実測` 欄を埋めて、この値を教えてください (or 自分で .scad に転記)。
2. 私が `[MEASURE]`/`[VERIFY]` 変数へ反映 → `export-stl.sh` で確定版 STL 生成。
3. スナップクーポン → 本体の順でテストプリント。

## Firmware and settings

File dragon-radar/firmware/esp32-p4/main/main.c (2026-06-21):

#include <math.h>

#include "freertos/FreeRTOS.h"
#include "freertos/task.h"
#include "esp_log.h"
#include "driver/gpio.h"
#include "lvgl.h"

#include "bsp/esp-bsp.h"
#include "bsp/display.h"
#include "bsp/esp32_p4_wifi6_touch_lcd_xc.h"

#include "ui/radar_view.h"
#include "ui/theme.h"
#include "uwb/uwb_uart.h"
#include "uwb/uwb_filter.h"
#include "game/game_state.h"
#include "audio/audio_player.h"
#include "imu/imu_bno086.h"

static const char *TAG = "dragon-radar";

/* IMU heading -> world-frame azimuth. With the BNO086 the UWB azimuth (device-frame)
 * is rotated by the device heading so the blip holds its real-world bearing as you
 * turn the radar. Sign/offset are empirical (IMU mount orientation) - flip if the
 * blip rotates the wrong way. */
#define IMU_HEADING_SIGN        (+1.0f)
#define IMU_HEADING_OFFSET_DEG  (0)

/* Front-panel momentary button (active-low, internal pull-up): cycles the radar
 * display range 1m -> 3m -> 10m, like the original Dragon Radar's zoom. */
#define BUTTON_GPIO  22

static void handle_game_event(game_event_t ev)
{
    switch (ev) {
    case GAME_EV_IN_REACH:
        ESP_LOGI(TAG, "ball in reach");
        audio_player_cue(AUDIO_CUE_PROXIMITY);
        break;
    case GAME_EV_COLLECTED:
        ESP_LOGI(TAG, "ball COLLECTED (%u/%u)",
                 (unsigned)game_get_collected(), (unsigned)DR_GAME_TARGET_BALLS);
        audio_player_cue(AUDIO_CUE_COLLECTED);
        break;
    case GAME_EV_ALL_COLLECTED:
        ESP_LOGI(TAG, "ALL BALLS COLLECTED -> summoning!");
        audio_player_cue(AUDIO_CUE_SUMMON);
        break;
    default: break;
    }
}

static void uwb_task(void *arg)
{
    (void)arg;
    uwb_measurement_t m;
    int seen = 0;
    while (1) {
        if (uwb_uart_recv(&m, 1000)) {
            float heading = 0.0f;
            bool have_heading = imu_bno086_get_heading(&heading);
            if (have_heading) {
                /* device-frame azimuth -> world frame so the blip is rotation-stable */
                int wa = (int)lroundf((float)m.azimuth_deg + IMU_HEADING_SIGN * heading)
                         + IMU_HEADING_OFFSET_DEG;
                while (wa >= 180) wa -= 360;
                while (wa < -180) wa += 360;
                m.azimuth_deg = (int16_t)wa;
            }
            if (!uwb_filter_apply(&m)) continue;
            bsp_display_lock(-1);
            radar_view_set_tag(&m);
            bsp_display_unlock();
            game_on_measurement(&m);
            handle_game_event(game_poll_event());
            if ((++seen % 10) == 0) {
                ESP_LOGI(TAG, "tag=%u d=%u mm az=%d el=%d hd=%.0f%s collected=%u (n=%d)",
                         (unsigned)m.tag_id, (unsigned)m.distance_mm,
                         m.azimuth_deg, m.elevation_deg,
                         heading, have_heading ? "" : "(no-imu)",
                         (unsigned)game_get_collected(), seen);
            }
        }
    }
}

static void button_task(void *arg)
{
    (void)arg;
    gpio_config_t io = {
        .pin_bit_mask = 1ULL << BUTTON_GPIO,
        .mode         = GPIO_MODE_INPUT,
        .pull_up_en   = GPIO_PULLUP_ENABLE,
        .pull_down_en = GPIO_PULLDOWN_DISABLE,
        .intr_type    = GPIO_INTR_DISABLE,
    };
    gpio_config(&io);
    int last = 1;
    while (1) {
        int v = gpio_get_level(BUTTON_GPIO);
        if (last == 1 && v == 0) {                    /* falling edge = press */
            vTaskDelay(pdMS_TO_TICKS(30));            /* debounce */
            if (gpio_get_level(BUTTON_GPIO) == 0) {
                bsp_display_lock(-1);
                uint16_t r = radar_view_cycle_range();  /* zoom: 1m -> 3m -> 10m */
                bsp_display_unlock();
                ESP_LOGI(TAG, "button: range -> %u mm", (unsigned)r);
                audio_player_cue(AUDIO_CUE_PROXIMITY);
                while (gpio_get_level(BUTTON_GPIO) == 0) vTaskDelay(pdMS_TO_TICKS(20)); /* wait release */
            }
        }
        last = v;
        vTaskDelay(pdMS_TO_TICKS(20));
    }
}

void app_main(void)
{
    ESP_LOGI(TAG, "Dragon Radar UWB (ESP32-P4 + Waveshare 3.4C) - boot");

    bsp_display_cfg_t cfg = {
        .lv_adapter_cfg   = ESP_LV_ADAPTER_DEFAULT_CONFIG(),
        .rotation         = ESP_LV_ADAPTER_ROTATE_0,
        .tear_avoid_mode  = ESP_LV_ADAPTER_TEAR_AVOID_MODE_TRIPLE_PARTIAL,
        .touch_flags      = { .swap_xy = 0, .mirror_x = 0, .mirror_y = 0 },
    };
    bsp_display_start_with_config(&cfg);
    bsp_display_backlight_on();

    bsp_display_lock(-1);
    radar_view_create(lv_screen_active());
    bsp_display_unlock();

    /* IMU shares the BSP I2C bus (touch already brought it up). Optional: if the
     * BNO086 is absent, init fails gracefully and UWB/touch keep working. */
    if (imu_bno086_init(bsp_i2c_get_handle()) == ESP_OK) {
        imu_bno086_start_task();
    }

    game_init();
    audio_player_init();
    uwb_uart_init();
    xTaskCreate(uwb_task, "uwb_rx", 4096, NULL, 5, NULL);
    xTaskCreate(button_task, "button", 3072, NULL, 4, NULL);

    /* app_main must NOT return here: doing so tears down the display on this
     * BSP/LVGL-adapter setup (confirmed 5/19 — static UI vanished without this). */
    while (1) {
        vTaskDelay(pdMS_TO_TICKS(1000));
    }
}

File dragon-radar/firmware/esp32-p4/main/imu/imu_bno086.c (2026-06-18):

#include "imu_bno086.h"

#include <string.h>
#include <math.h>

#include "freertos/FreeRTOS.h"
#include "freertos/task.h"
#include "esp_log.h"

static const char *TAG = "imu_bno086";

#define BNO_ADDR        0x4B
#define BNO_I2C_HZ      100000      /* conservative; shared bus, low data rate */

/* SHTP channels */
#define CH_CMD          0
#define CH_EXEC         1
#define CH_CONTROL      2
#define CH_REPORTS      3

/* SH-2 report IDs */
#define SET_FEATURE_COMMAND             0xFD
#define REPORTID_ROTATION_VECTOR        0x05    /* absolute (uses magnetometer / true-ish north) */
#define REPORTID_GAME_ROTATION_VECTOR   0x08    /* relative yaw, no magnetometer (robust near magnets) */

/* Game Rotation Vector by default: immune to the USB/speaker magnets near the IMU,
 * and rotation-stability only needs *relative* yaw. Switch to ROTATION_VECTOR for
 * magnetic-north referenced heading (needs figure-8 mag calibration). */
#ifndef IMU_FEATURE_ID
#define IMU_FEATURE_ID  REPORTID_GAME_ROTATION_VECTOR
#endif

#define REPORT_INTERVAL_US  20000   /* 50 Hz */

static i2c_master_dev_handle_t s_dev = NULL;
static volatile bool  s_ok  = false;
static volatile float s_yaw = 0.0f;
static uint8_t s_seq[6] = {0};

/* Send one SHTP packet: 4-byte header + payload. */
static esp_err_t shtp_send(uint8_t channel, const uint8_t *data, uint16_t len)
{
    uint8_t pkt[24];
    uint16_t total = len + 4;
    if (total > sizeof(pkt)) return ESP_ERR_INVALID_SIZE;
    pkt[0] = total & 0xFF;
    pkt[1] = (total >> 8) & 0xFF;
    pkt[2] = channel;
    pkt[3] = s_seq[channel]++;
    memcpy(pkt + 4, data, len);
    return i2c_master_transmit(s_dev, pkt, total, 100);
}

/* SH-2 "Set Feature Command" -> enable a periodic sensor report. */
static esp_err_t enable_feature(uint8_t report_id, uint32_t interval_us)
{
    uint8_t p[17] = {0};
    p[0] = SET_FEATURE_COMMAND;
    p[1] = report_id;
    /* p[2] flags, p[3..4] change sensitivity = 0 */
    p[5] = interval_us & 0xFF;
    p[6] = (interval_us >> 8) & 0xFF;
    p[7] = (interval_us >> 16) & 0xFF;
    p[8] = (interval_us >> 24) & 0xFF;
    /* p[9..12] batch interval, p[13..16] sensor config = 0 */
    return shtp_send(CH_CONTROL, p, sizeof(p));
}

/* Read one SHTP packet (SparkFun-style: header re-sent per read transaction).
 * Stores up to cap payload bytes into out. Returns false on I2C error / no data. */
static bool read_packet(uint8_t *out, int cap, int *payload_len, uint8_t *channel)
{
    uint8_t hdr[4];
    if (i2c_master_receive(s_dev, hdr, 4, 100) != ESP_OK) return false;
    uint16_t len = (uint16_t)(hdr[0] | (hdr[1] << 8)) & 0x7FFF;   /* strip continuation bit */
    *channel = hdr[2];
    if (len < 4 || len > 1024) { *payload_len = 0; return true; } /* 0 / 0xFFFF => no data */

    int remaining = len - 4;
    *payload_len = remaining;
    int copied = 0;
    uint8_t tmp[68];
    while (remaining > 0) {
        int chunk = remaining > 60 ? 60 : remaining;
        if (i2c_master_receive(s_dev, tmp, chunk + 4, 100) != ESP_OK) return false;
        /* tmp[0..3] is the re-sent header; payload continues at tmp[4]. */
        int space = cap - copied;
        if (space > 0) {
            int n = chunk < space ? chunk : space;
            memcpy(out + copied, tmp + 4, n);
            copied += n;
        }
        remaining -= chunk;
    }
    return true;
}

/* Parse a rotation-vector report's quaternion (Q14) -> yaw degrees. */
static bool parse_rotation_vector(const uint8_t *payload, int plen, float *yaw_out)
{
    int idx = 0;
    if (plen > 0 && payload[0] == 0xFB) idx = 5;   /* skip 0xFB timebase + 4-byte delta */
    if (idx + 12 > plen) return false;
    if (payload[idx] != IMU_FEATURE_ID) return false;

    int16_t qi = (int16_t)(payload[idx + 4] | (payload[idx + 5] << 8));
    int16_t qj = (int16_t)(payload[idx + 6] | (payload[idx + 7] << 8));
    int16_t qk = (int16_t)(payload[idx + 8] | (payload[idx + 9] << 8));
    int16_t qr = (int16_t)(payload[idx + 10] | (payload[idx + 11] << 8));

    const float Q = 1.0f / 16384.0f;            /* Q14 fixed point */
    float i = qi * Q, j = qj * Q, k = qk * Q, r = qr * Q;
    /* yaw (rotation about Z) */
    float yaw = atan2f(2.0f * (r * k + i * j), 1.0f - 2.0f * (j * j + k * k));
    *yaw_out = yaw * 57.2957795f;
    return true;
}

esp_err_t imu_bno086_init(i2c_master_bus_handle_t bus)
{
    if (bus == NULL) return ESP_ERR_INVALID_ARG;

    if (i2c_master_probe(bus, BNO_ADDR, 200) != ESP_OK) {
        ESP_LOGW(TAG, "BNO086 not found at 0x%02X -> IMU disabled (UWB/touch unaffected)", BNO_ADDR);
        return ESP_ERR_NOT_FOUND;
    }

    i2c_device_config_t dc = {
        .dev_addr_length = I2C_ADDR_BIT_LEN_7,
        .device_address  = BNO_ADDR,
        .scl_speed_hz    = BNO_I2C_HZ,
    };
    esp_err_t e = i2c_master_bus_add_device(bus, &dc, &s_dev);
    if (e != ESP_OK) {
        ESP_LOGW(TAG, "add_device failed (%s) -> IMU disabled", esp_err_to_name(e));
        return e;
    }

    ESP_LOGI(TAG, "BNO086 @0x%02X found; enabling report 0x%02X @ %d Hz",
             BNO_ADDR, IMU_FEATURE_ID, 1000000 / REPORT_INTERVAL_US);

    /* Drain boot advertisement / init packets. */
    uint8_t buf[64]; uint8_t ch; int plen;
    for (int n = 0; n < 10; n++) { read_packet(buf, sizeof(buf), &plen, &ch); vTaskDelay(pdMS_TO_TICKS(3)); }

    enable_feature(IMU_FEATURE_ID, REPORT_INTERVAL_US);
    return ESP_OK;
}

bool imu_bno086_ok(void) { return s_ok; }

bool imu_bno086_get_heading(float *yaw_deg)
{
    if (!s_ok) return false;
    if (yaw_deg) *yaw_deg = s_yaw;
    return true;
}

static void imu_task(void *arg)
{
    (void)arg;
    uint8_t buf[64]; uint8_t ch; int plen;
    uint32_t got = 0, ticks = 0;
    while (1) {
        if (read_packet(buf, sizeof(buf), &plen, &ch) && plen > 0 && ch == CH_REPORTS) {
            float yaw;
            if (parse_rotation_vector(buf, plen, &yaw)) {
                s_yaw = yaw;
                s_ok = true;
                got++;
            }
        }
        /* Re-arm the feature if nothing arrived in the first ~2 s (enable may have
         * landed during the boot advertisement). */
        if (!s_ok && (++ticks % 100) == 0) {
            enable_feature(IMU_FEATURE_ID, REPORT_INTERVAL_US);
        }
        if ((ticks % 250) == 0) {
            ESP_LOGI(TAG, "heading=%.1f deg  ok=%d  samples=%u", s_yaw, (int)s_ok, (unsigned)got);
        }
        ticks++;
        vTaskDelay(pdMS_TO_TICKS(20));
    }
}

void imu_bno086_start_task(void)
{
    if (s_dev == NULL) return;   /* init failed -> no task */
    xTaskCreate(imu_task, "imu_rx", 4096, NULL, 4, NULL);
}

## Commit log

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2026-05-03 dragon-radar/ プロジェクト初期化 + Phase 2 LVGL レーダー UI
    - ESP-IDF v5.3.2 プロジェクト一式 (CMakeLists, sdkconfig.defaults, partitions.csv)
    - LVGL 9.2 で円形ドラゴンレーダー UI 実装 (同心円3本+十字+1.5秒スイープ+7色光点)
    - ダミーデータデモタイマで光点が動くところまで動作確認
    - uwb/game/audio/storage/display_init は最小スタブ (Path C で順次実装)
    - tools/uart_sniffer.py: PC で QN9090 UART を覗く用 (Phase 1a/Path C デバッグ)
    - ESP-IDF ビルド成功 (dragon_radar.bin 366KB)
    [partitions.csv]
2026-05-03 dragon-radar-spec.md を Path C 戦略に全面書き換え + 関連 docs 整備
    - 採用方針: Path C (QN9090 にカスタム FW、ESP32 ↔ QN9090 は UART)
    - Path A は 2DK Initiator 固定で詰む、Path B は 2BP 1個で破壊リスク高、と判断
    - 二段構え: 5月中 Path C で 6/22 応募 → 7-8月 Path B 移植 → 9/5-6 Maker Faire
    - Phase 0-7 を再定義 (校正値バックアップ → MCUXpresso 開発 → ASCII プロトコル → 2DK Responder 化 → 演出 → 応募 → Path B 移植 → 7タグ拡張)
    - ハード構成を現有 3 機 (2BP×1 + 2DK×2) に修正、9月用 2DK×5 追加発注は応募後
    - dragon-radar/README.md と docs/2bp-protocol.md を Path C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
2026-05-11 ESP32-P4 + LED ボタン採用、スケジュール 5/11 起算に修正
    - 表示ボード: ESP32-S3-Touch-LCD-1.85 → ESP32-P4-WIFI6-Touch-LCD-3.4C へ格上げ (5/11 着、800×800 / ø86mm 画面)
    - UI 三段構え確定: 物理ボタン (MKBKLLJY ø12mm 緑 LED) + 10 点タッチ + デュアルマイク音声トリガ
    - スピーカー: 同梱大型品は使わず uxcell ø20mm 8Ω 1W に交換 (5/12 着予定)
    - スケジュール: 5/3 起算 → 5/11 起算に全面更新、GW 終了済を反映
    - firmware/2bp-fw/ + firmware/2dk-fw/ のディレクトリ + README 追加 (Path C 開発の置き場)
    - firmware/2bp-config/.gitignore を強化 (sdk/ も含めて NDA 配下全除外)
2026-05-13 firmware/esp32-p4/: ESP32-P4 (Waveshare 3.4C) 移植 + Bandai 風レーダー UI
    - ESP-IDF v5.5.4 + esp32p4 ターゲット、Waveshare BSP (waveshare/esp32_p4_wifi6_touch_lcd_xc:*) 利用
    - main.c: bsp_display_start_with_config() 一発で MIPI-DSI + JD9365 LCD + GT911 タッチ + LVGL adapter まで自動初期化
    - ui/radar_view.c: 360x360 → 800x800 にスケール。光点 14→30px、リング半径 60/120/180→133/267/390、線幅 1→2px
    - ui/theme.{c,h}: Bandai 玩具/アニメ準拠の色 (背景=深緑 #1A5C2E、グリッド=暗緑、スイープ=明緑 #80FF80、ドット=金色グラデ #FFC800-#FF8C00)
    - radar_view.c: CRT 風 40px グリッド + 中央に金色三角ポイン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
    [partitions.csv]
2026-05-13 radar UI を Bandai 公式 (玩具版) に寄せる: 緑背景 + 太黒グリッド + 塗潰しコーラル三角
    - DR_COLOR_BG: #1A5C2E → #2A9040 に明度上げ、鮮やかな緑に
    - DR_COLOR_GRID: 新設 #001008 (ほぼ黒)、グリッド線をくっきり太く (1→2px, opacity 40→80%, ピッチ 40→50px)
    - 同心円 / 十字を radar_view から除去 (Bandai はグリッドのみで距離感)
    - DR_COLOR_POINTER: #FF6E50 コーラルを新設
    - draw_center_pointer をスキャンライン埋めの塗潰し三角形に書換 (旧: lv_line アウトライン)
    - スイープ色 #80FF80 → #A0FFB0 で明度微増
    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
2026-05-29 Phase 2d-5 完了: 実機 + LCD で UWB 光点表示を確認
    実装時に踏んだバグ 2 件を修正:
    - uwb_uart.c: tag_id = t + 1 (QN9090 の 0-based measurement index を
    radar_view の 1-based tag_id に変換)。set_tag が t=0 を drop していた。
    - main.c: app_main 末尾に while(1) を復活。この BSP/esp_lvgl_adapter
    構成では app_main が return すると static UI ごと表示が消えるため。
    spec に運用知見を追記: 2BP カスタム FW は 5 分で ranging 停止、
    再ペアは 2DK→2BP の順でリセット。Phase 3 の FW 再ビルドで連続 ranging 化予定。
    [main.c, uwb_uart.c]
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2026-05-30 筐体 v0.1: OpenSCAD パラメトリック 3部品クラムシェル (3.4C ø115 実寸ベース)
    - ガラス外形ø115/有効ø87.6 を実寸調査で確定 (仕様書のø110想定を訂正)
    - 前面ベゼル + 本体タブ + バックカバー、ボードmockで嵌合確認
    - マウント穴/コネクタ角度は[MEASURE]変数化 (現物到着後に確定)
    - 全パート STL/PNG レンダリング検証済
    [dragon-radar-enclosure.scad]
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2026-05-30 筐体 v0.2: 固定方式を確定 (ベゼル環状スナップ + バックM3ネジ)
    - ベゼル⇔本体: 段付きトング+連続ビード/溝の環状スナップ (前面ネジ無し)
    - バックカバー: 後方空洞ボスに M3 セルフタップ×4
    - v0.1嵌合バグ修正 (スカート/壁干渉・ガラス押さえ面欠落)、外周ø121面一
    - clip=true で半割り断面確認、全パートSTL/PNG検証済
    [dragon-radar-enclosure.scad]
2026-05-30 筐体 v0.3: 天面ボタンタレットを実装 (MKBKLLJY ø12)
    - モジュールと内壁の隙間~4mmでは端子が干渉するため、天面に中空タレットを設置
    - タレット: 中ぐり(ナット/端子逃げ) + 端面パネル穴ø12.3 + 配線通路ø5
    - ベゼル/本体の合わせ目をまたぐ → ベゼルに逃げノッチ
    - 端子はタレット内に収め、配線のみ環状隙間→後方空洞へ
    - ボタン全長/端子長/パネル厚は[VERIFY](現物実測で確定)
    - 全パートSTL/PNG検証済
    [dragon-radar-enclosure.scad]
2026-05-30 筐体: スナップ試しクーポン + STL一括書き出し (B-1/B-3)
    - coupon_body/coupon_bezel: 嵌合部を底側55°アークで切出し(実部品と同期)
    - フル印刷前にPLA実機でビード乗り越え/fit_gap/リードインを検証する小片
    - export-stl.sh で印刷用STL一括生成 (stl/ はgit管理外)
    - README: クーポン手順 + 印刷向き/サポート指針を追記
    [dragon-radar-enclosure.scad]
2026-05-30 筐体 v0.4: フィンガースカラップ + ネジボス浮き修正
    - 3/9時(0/180°)に親指レスト: 薄壁のため肉盛りレンズ+浅い凹みで最薄~2.4mm確保
    - ベゼル占有域と干渉しないようz=-14.5に配置、scallop_*で調整可
    - 副次: placeholderコネクタを底側(250/270/290°)に集約
    - 🐞修正: ネジボスが内壁に0.5mm届かず浮きソリッド化(CGAL Volumes=6)
    → screw_pcdを外側へ寄せ壁と一体化(Volumes=2=単一ソリッド)
    - 全パートmanifold(Simple:yes)確認済
    [dragon-radar-enclosure.scad]
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2026-05-31 実測反映: 背面は四角キャリア基板 65×86 (丸PCB想定を訂正)
    - 前面=丸ディスプレイø115 / 背面=四角キャリア65×86 と判明 (現物実測)
    - 対角~108mm で丸ガラスø115内に収まる → 丸筐体ø121はそのまま有効
    - board_mock を丸ディスプレイ+四角キャリアに修正
    - マウント穴は四隅ではない → mount_holes 実測リスト方式に変更
    - board_stack_th 15→14, MEASURE.md を長方形キャリア用に更新
    [dragon-radar-enclosure.scad]
2026-05-31 実測反映: マウントネジ4本を確定 (上下非対称な台形)
    - 列間X=83.6(外形込み) / 左列Y間隔32 / 右列Y間隔39
    - 上端→上ネジ 左8.6/右8.3 → 上寄り非対称配置
    - 丸外形ø115縁から上ネジ約9-10mm内側で実測コメントと整合
    - board_mock に4点反映 (外形込み→穴芯はスタンドオフ径ぶん後で微調整)
    [dragon-radar-enclosure.scad]
2026-05-31 向き確定: carrier_angle=180 (USB-C下出し) + 競合回避
    - USB-C→底270 / USB-A→右0 / microSD→左180 にコネクタ開口を配置
    - conn_z をキャリア深さ中央(-10)に補正
    - スカラップを 0/180→30/150 に移設(コネクタと競合回避、上側親指位置)
    - 本体 単一ソリッド維持(Simple:yes)
    [dragon-radar-enclosure.scad]
2026-05-31 ボード固定: バックカバーに台形ボス4本+背面ザグリネジ (二段締め対応)
    - カラーでボード⇔ディスプレイ締結済の上に、バックから4本で筐体固定
    - ボスはバックカバーから前方へ伸びキャリア背面(z=-14)を受ける
    - 外側からザグリ+貫通、先で台形マウント穴へ締結 (carrier_angle追従)
    - board_screw_dia=2.5等は[VERIFY]、バックカバー単一ソリッド維持
    [dragon-radar-enclosure.scad]
2026-05-31 修正: スナップビードをスカートに0.8mm食い込ませ一体化
    - bezel が Volumes=3 (ビードが面一接触で別ソリッド扱い) だった
    - bead_inward の外縁を Ri→Ri+0.8 にしてスカートと確実に融合
    - bezel 単一ソリッド化 (Volumes=2 / Simple:yes)、印刷で外れる不具合を防止
    [dragon-radar-enclosure.scad]
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2026-05-31 ボタン実測反映: タレット短縮 + パネル厚確定 (v0.6)
    - 実測: 全長24 / 頭1.7 / 頭〜ナット6mm (写真IMG_0696)
    - turret_cap_th 3.0→2.0 (頭1.7+パネル+ナット=6 制約)
    - turret_protrude 18→14 (配線済で端子は柔→金属取付部のみ保持、端子は隙間へ)
    - 残[VERIFY]: バレル径・六角ナット外径 (標準ø12なら現状値で収まる)
    - MEASURE.md §4 を確定値で更新、全パート単一ソリッド維持
    [dragon-radar-enclosure.scad]
2026-05-31 fix: タレット180度バグ修正 + ボタン嵌合テスト片
    - turret_*の基準軸が+Yでbutton_angle合成により実角度90+90=180度にズレ
    microSD開口(180)と衝突していた
    - 基準を+Xに統一(コネクタ/スカラップと同じ) button_angle=90で正しく天面
    - coupon_button (天面タレット周辺を実ジオメトリで切出す) 追加
    - 全パート単一ソリッド維持
    [dragon-radar-enclosure.scad]
2026-05-31 apply pre-print review fixes: snap tongue cut-through (critical), seating shelf, scallop bleed, USB-A width, cap thickness
    [dragon-radar-enclosure.scad]
2026-05-31 fix: connector opening 0.2mm outer membrane regression (wall increase side-effect) + docs
    regression-verify workflow (3 confirmed):
    - [CRITICAL regression] connector_cutout reached 0.2mm short of R_out leaving an outer skin on all 3 connectors (plug blocked) -> wall-independent cut R_in-2..R_out+1; ray-cast confirms USB-A/microSD/USB-C fully open
    - [LOW] stale comment outer_dia 121->122.6
    - docs: README v0.7 / spec outer dia 122.6 / coupon_button in export
    - all 6 parts single solid
    [dragon-radar-enclosure.scad]
2026-05-31 DMM nylon (PA12) preset + 2 manifold fixes
    - process switch: dmm_nylon (公差±0.3向け) / fdm_pla
    - dmm_nylon: wall3.6/fit_gap0.45/snap_bead1.1/button_dia12.6
    残壁1.0/スカート1.05/保持代0.65(±0.3公差耐性)/ビードはガラス側に出ず
    - 🐞 board固定ボスがプレートと0.01mm重なりのみで脆弱→z0貫通で一体化、boss径6→7.5(頭ザグリ周囲≥1.15mm)
    - 🐞 nylonでバックカバー嵌合リップ半径と閉じネジ穴外縁が一致し退化分裂(Volumes6)→リップ-1.5で回避
    - 両プロセス 全6パート単一ソリッド確認
    [dragon-radar-enclosure.scad]
2026-06-14 FDM/PLA向け仕上げ: ベゼル環状スナップをバネ爪化(12分割)+溝幅太+リードイン軽め, ナイロンプリセット撤去(wall3.2/fit_gap0.5/bead0.8/button12.3), クーポン長尺化(68°@223 boss/コネクタ回避)
    [dragon-radar-enclosure.scad]
2026-06-14 スナップ確定(FDM/PLA実機検証): 薄壁版は保持せず→厚壁化 wall3.2→4.4/skirt1.5→2.2/bead0.8→1.2/gap0.5→0.30 (保持代0.9, 爪~1.9mm, 外径ø125)
    [dragon-radar-enclosure.scad]
2026-06-15 提案A: バックカバーの基板固定ボス/ネジを撤去し純粋な蓋に(本体M3×4+通気のみ)。基板はディスプレイ側スタンドオフ+ベゼル押さえで保持。穴アラインずれ問題を解消
    [dragon-radar-enclosure.scad]
2026-06-15 嵌合2件修正: ①スカラップZ上端 -1→-(tongue_h+2)=-9 でベゼル域への肉盛り侵入解消(2時/10時で嵌まらない不具合) ②バック嵌合リップ inner_dia-2*fit_gap-1.5(緩い+ネジ穴欠け)→inner_dia-0.5(スナグ&ネジ穴内包)
    [dragon-radar-enclosure.scad]
2026-06-15 ドラゴンボール(UWBタグ2DK球体ケース)パラメトリック設計: φ70中空(内φ65.6)/星1-7(既定4★)/半球2分割+位置決めリップ。Photon M3レジン(かえんオレンジ)向け、STL書出可
    [dragon-ball.scad]
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2026-06-18 ドラゴンボールを一星球(★1)に確定: DigiKey Make ONE Challenge → 一星球。star_count 4→1 / star_d 8→12(単独星を映えさせる)。動作する2DKタグが#2の1個である現実とも整合。STL(dragon-ball-top-1star)出力済
    [dragon-ball.scad]
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2026-06-18 バックカバー削り不要化+ピン逃がし窓: ①嵌合リップが本体ボス(PCD111.7/ø7.5)と干渉→リップにボス逃げ(ø10)+ネジ穴貫通4.6/ザグリ7.0で遊び拡大 ②USB-C側(270°)に40ピンヘッダ/ジャンパ逃がし窓(コネクタがback_clear=8超で閉まらない問題)。pin_relief/back_boss_clear等パラメータ化
    [dragon-radar-enclosure.scad]
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2026-06-21 ドラゴンボール: ヘッドレス樹脂印刷用に排液穴(任意param drain_holes, 既定off)+平置き向き(part=bottom_print/top_print)追加。PrusaSlicer CLI→UVtoolsで.pm3生成に使用。最終ボールはdrain_holes=offで穴なし
    [dragon-ball.scad]
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2026-06-22 バックカバー: ピン逃がし窓を右(+X)へ延長=右下(315°)ネジ穴の手前まで(pin_relief_ext=12→右端X=33, ボス逃げ34.5の手前/左端維持・符号で左右反転可)。実機で右がもう少し必要→次回印刷用に反映(今回は削り対応)
    [dragon-radar-enclosure.scad]
2026-06-22 レーダー表示: 上下(前後)反転を修正(polar_to_cartesian の cos 符号を反転、左右は不変)。実機で正面=上を確認・屋外で実ボール捜索も成功
